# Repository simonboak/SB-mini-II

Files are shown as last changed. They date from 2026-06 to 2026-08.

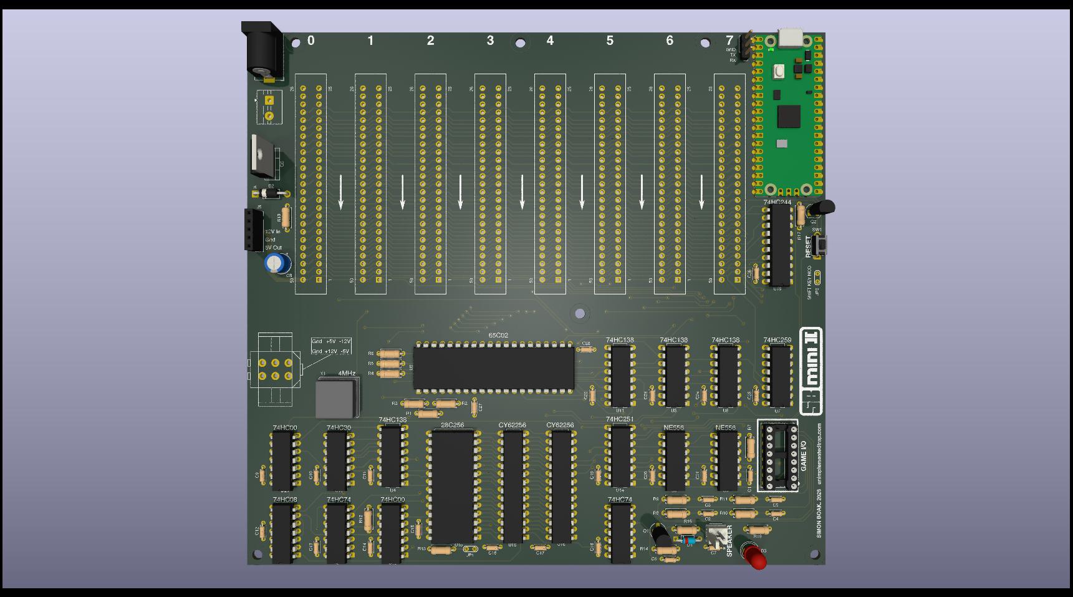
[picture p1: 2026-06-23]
Images/SB mini II Board Render.jpg

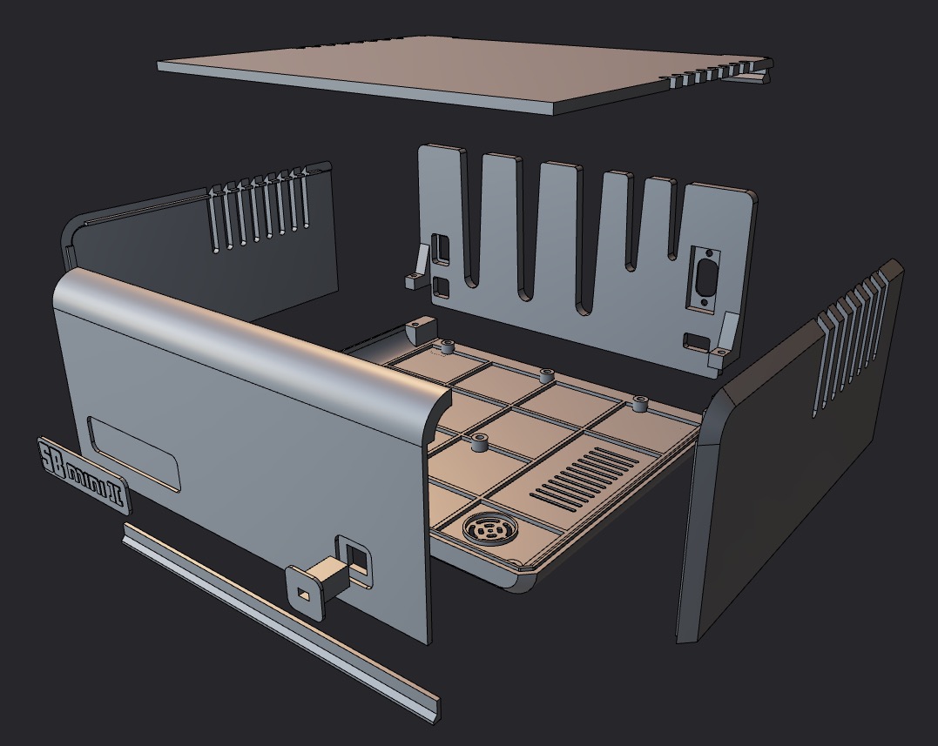
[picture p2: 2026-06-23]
Enclosure/Exploded View.jpg

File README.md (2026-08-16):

# SB mini II
A homebrewed Apple II clone. [Read more on the blog post](https://unimplementedtrap.com/sb-mini-ii-apple-ii-clone/)

SB mini II Logo

SB mini II cutaway

## Hardware Overview

- The CPU is a standard 65C02 running at near 1.024 MHz (the original Apple II ran at 1.023 for the 60 Hz models), after dividing the 4.096 MHz crystal by 4.
- The 12kB ROM image is placed on the 32k EEPROM. Because there's spare room on this chip a jumper allows for selecting the high or low half of the ROM chip, so I've placed Ardian Black's [Deadtest](https://github.com/misterblack1/appleII_deadtest) program in there.
- 48kB of RAM is accomplished by using one and half 32kB SRAM chips. Figured this was easier to use matching chipd than it was to use a 32kb + 16kB chip.
- Address decoding works exactly like the real Apple II. This was mostly based on the schematics in _Understanding The Apple II_ by Jim Sather.
- In Addition to the I/O slots, this has:
  - Speaker: matching the genuine Apple II
  - Game I/O: as the NE558 quad timer is hard to find, I've [implemented this replacement using a pair of 556 chips](https://github.com/roybaer/ne558_replacement).
  - Keyboard: a Raspberry Pi Pico provides a modern USB interface but electrically it connects to the Apple II in the same way as the original ASCII keyboard did. The Pi can also generate a reset pulse when pressing Control + Print Screen, and also performs a power-on reset for the system. The firmware for this is [in this project here](https://github.com/simonboak/SB-mini-II-Keyboard).
  - Graphics: there is absolutely no onboard hardware for displaying graphics. Instead you'll want to use an [Apple VGA Card](https://github.com/markadev/AppleII-VGA).
- Features deliberately missing:
  - Expansion slots do not provide the DMA, USER 1 or 7M clock signals.
  - The bus is not buffered: with a CMOS design this is less likely to be a problem (although no guarantees for interfacing with cards using 74LS logic).
  - There is no cassette input or output.
- These are the Revision 1 files. Rev 0 was a smaller board with no 5V regulation, only 7 slots and 32k on board RAM. The plan had been to leave out slot 0 and work out how to make full use of a second 32k RAM chip to have the full 64k without needing a language card, however this almost doubled the amount of circuitry needed.

SB mini II Board Render

## 3D Printed Case

Combining the design of the Apple II with the ProFile hard disk, the case requires a bit of assembly:

1. Print each piece with the flat side on the print bad (you could print the lid pieces as one if desired)
2. Glue the "tongue" into the slot along the bottom inside edge of the front piece. This will locate into the notch inside the front of the base.
3. Glue the top, front and sides together.
4. For the light pipe it was filled with hot glue to create a diffused lense with the LED glued in behind.
5. The base requires 8x M3 threaded inserts, 2 of which are for the back panel, the rest are the PCB mounts.
6. The 20mm speaker can be taped into the round hole in the base.

Assembled
Exploded View

### Rear with reset switch

An alernative file for the rear panel of the case is included. This contains a 7mm hole for a suitably sized push button switch.

### Rev 1 Update:

Alternative files are provided for the lid: this greatly reduces the radius of the curve on the front of the case. This should print better and without requiring so much filling and sanding, although it does depart from the styling inspiration of the ProFile hard disk.

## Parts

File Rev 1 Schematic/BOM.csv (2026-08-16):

Reference | Value | Qty
A1 | Raspberry Pi Pico 1 | 1
C1,C6,C7,C9,C10,C11,C12,C13,C14,C15,C16,C17,C18,C19,C20,C21,C22,C23,C24,C25,C26,C27,C28,C29 | 0.1µF | 24
C2,C3,C4,C5 | 22nF | 4
C8 | 470µF | 1
D1 | 1N914 | 1
D2 | 1N5240B | 1
D3 | 3 or 5mm power indicator LED | 1
J1 | GAME I/O: DIP-16 socket | 1
J2 | Pico Debug: 3 pin header | 1
J3 | PCB Barrel Jack | 1
J4 | Terminal block for power switch | 1
J5 | Pololu 5V 1A Step-Down Voltage Regulator (D24V10F5) | 1
J6 | Apple II Power Connector | 1
JP1 | HI ROM selector: 2 pin header | 1
JP2 | SHIFT KEY MOD: 2 pin header | 1
LS1 | Speaker 20mm 0.5W | 1
Q1 | MPSA13 | 1
Q2 | PN2222A | 1
Q3 | IRF5305 | 1
R1,R2,R3,R4,R5,R12 | 3k3 | 6
R6,R17 | 1k | 3
R7 | 2k5 | 1
R8,R9,R10,R11 | 100 | 4
R13 | 10K | 1
R14 | 47k | 1
R15 | 27 | 1
R18 | 100k | 1
R19 | 330 | 1
Slot1,Slot2,Slot3,Slot4,Slot5,Slot6,Slot7,Slot8 | 50 pin card edge connector | 8
SW1 | RESET: MJTP/PHAP33 tactile switch | 1
U1,U13 | 74HC74 | 2
U2 | 65C02 | 1
U3 | 74HC08 | 1
U4,U5,U6 | 74HC138 | 3
U7 | 74HC259 | 1
U8,U9 | NE556 | 2
U10 | 74HC30 | 1
U11 | 74HCT138 | 1
U12,U17 | 74HC00 | 2
U14 | 74HC251 | 1
U15 | 28C256 32k x 8 EEPROM | 1
U16,U18 | CY62256 32k x 8 SRAM | 2
U19 | 74HC244 | 1
Y1 | 4MHz square can crystal oscillator | 1

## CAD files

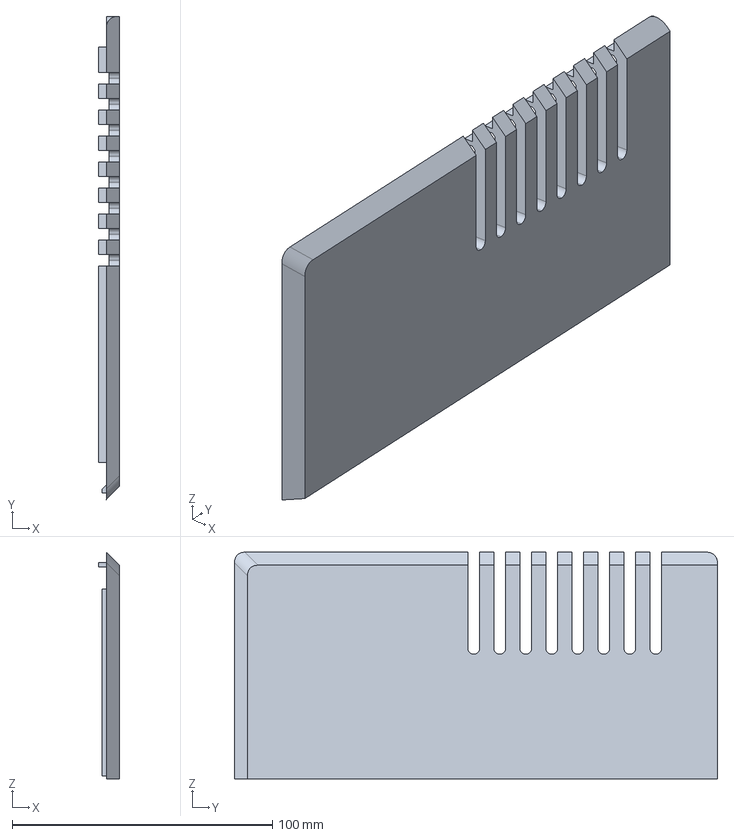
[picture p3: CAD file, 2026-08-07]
Enclosure/Lid Rev 1/Right Side - Rev 1.stp
8.00 x 185.7 x 87.1 mm

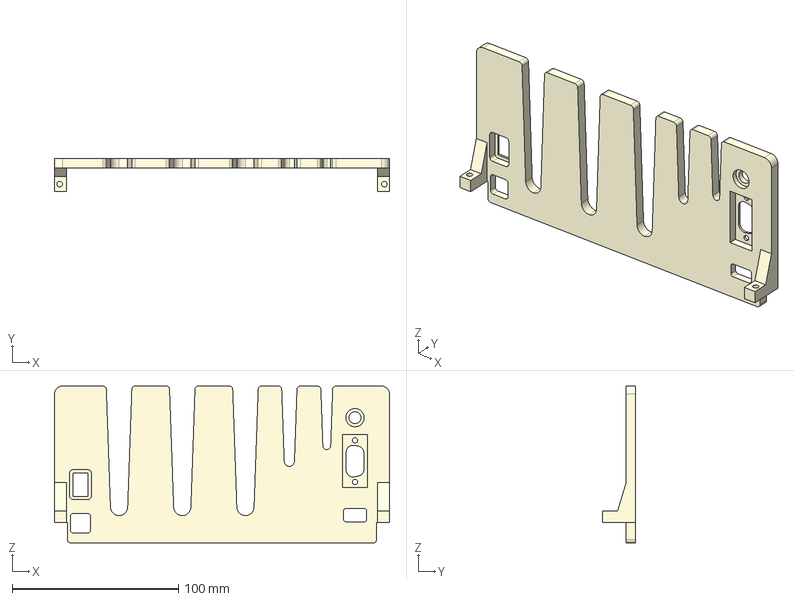
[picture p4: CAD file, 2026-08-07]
Enclosure/Rear with Reset Switch.stp
201.4 x 20.0 x 94.3 mm

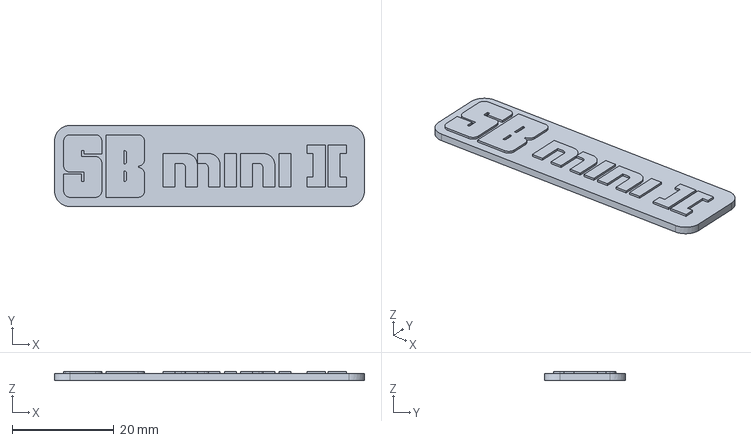
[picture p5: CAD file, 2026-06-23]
Enclosure/Badge.stp
61.0 x 16.0 x 1.80 mm

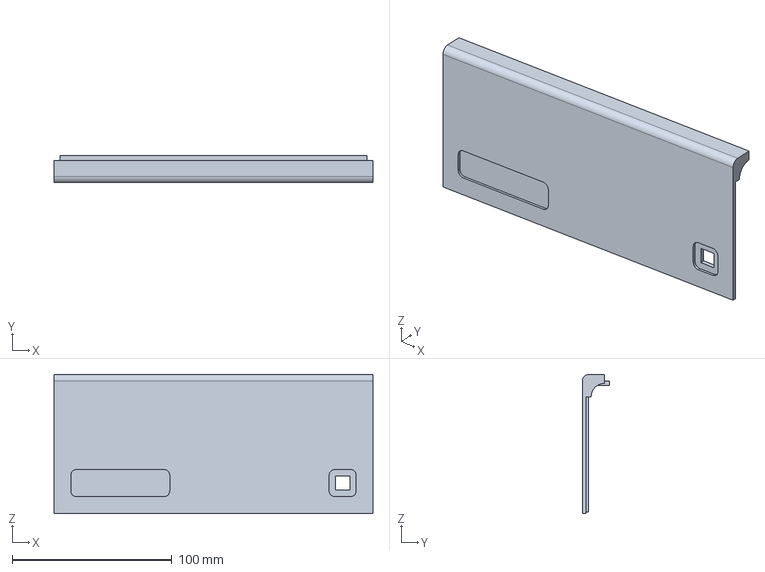
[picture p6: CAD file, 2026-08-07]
Enclosure/Lid Rev 1/Front - Rev 1.stp
199.8 x 17.1 x 87.1 mm

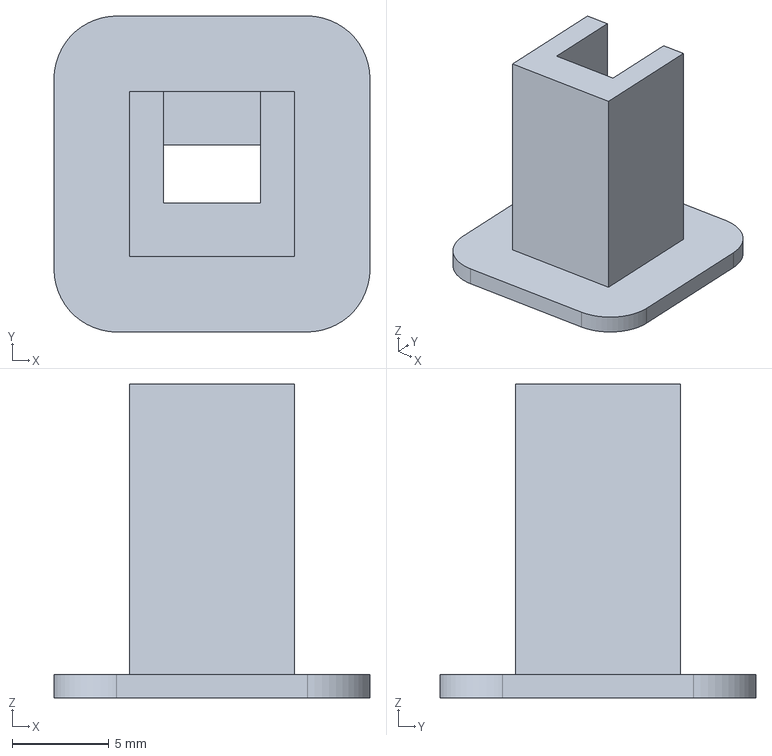
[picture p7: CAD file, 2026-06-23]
Enclosure/Light Pipe.stp
16.3 x 16.3 x 16.2 mm

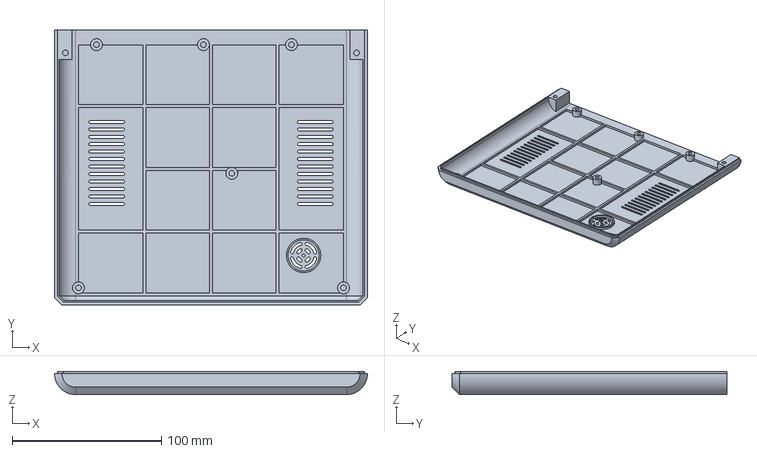
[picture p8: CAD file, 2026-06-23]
Enclosure/Base.stp
210.0 x 184.7 x 15.5 mm

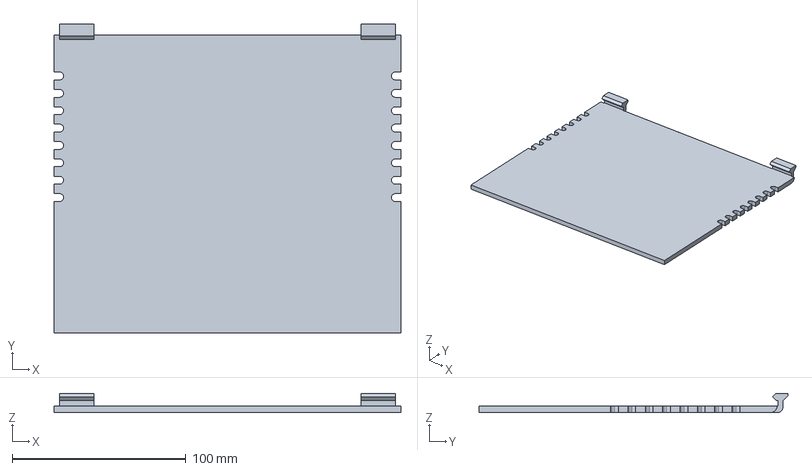
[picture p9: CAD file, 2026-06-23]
Enclosure/Lid Rev 1/Lid - Rev 1.stp
199.8 x 178.0 x 11.1 mm

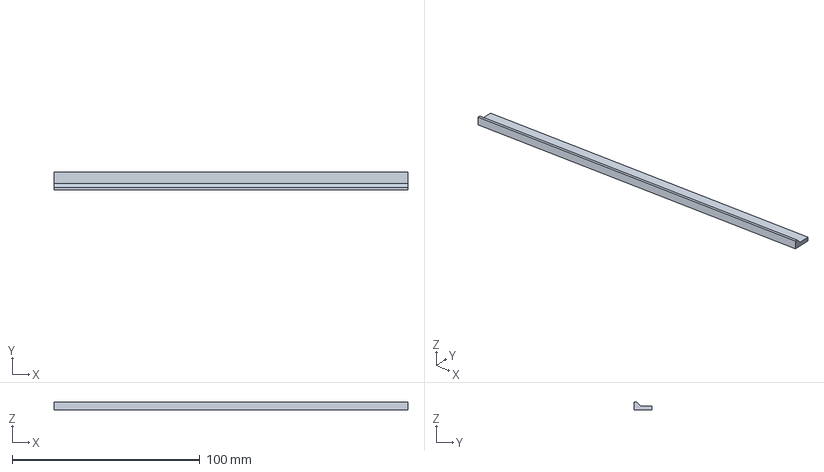
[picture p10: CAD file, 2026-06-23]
Enclosure/Lid Rev 1/Tongue - Rev 1.stp
188.6 x 9.50 x 4.14 mm

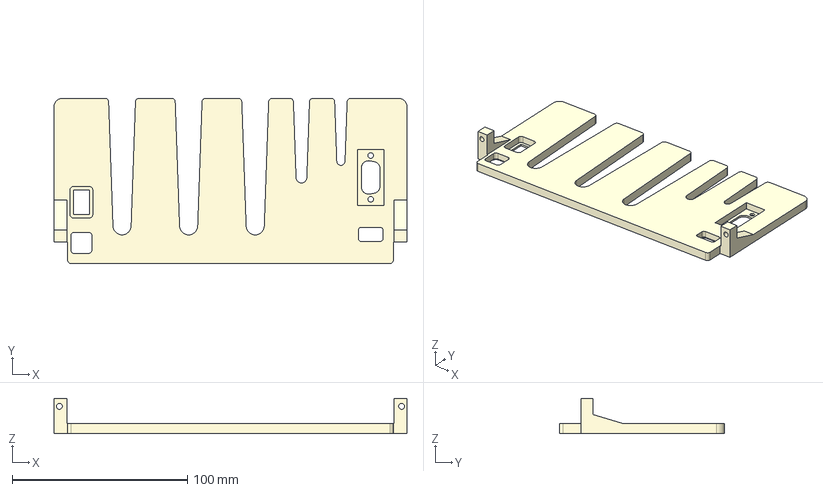
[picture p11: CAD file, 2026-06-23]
Enclosure/Rear.stp
201.4 x 94.4 x 20.0 mm

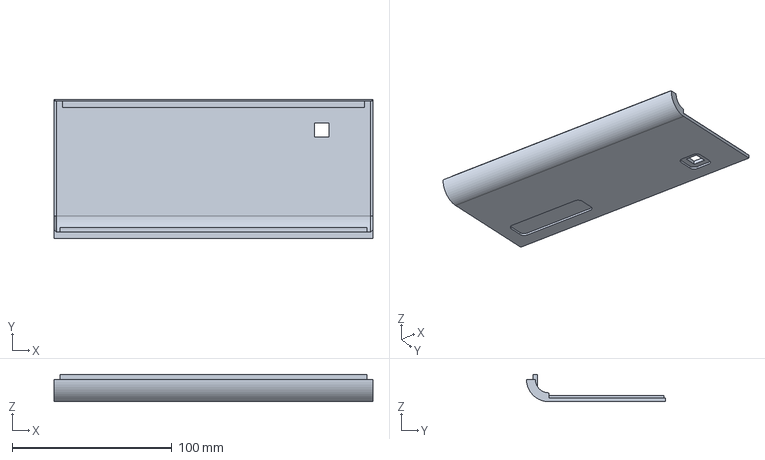
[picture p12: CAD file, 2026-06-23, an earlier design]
Enclosure/Lid Rev 0/Front.stp
199.8 x 87.1 x 17.1 mm

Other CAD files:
Enclosure/Lid Rev 1/Left Side - Rev 1.stp
Enclosure/Lid Rev 0/Left Side.stp
Enclosure/Lid Rev 0/Right Side.stp

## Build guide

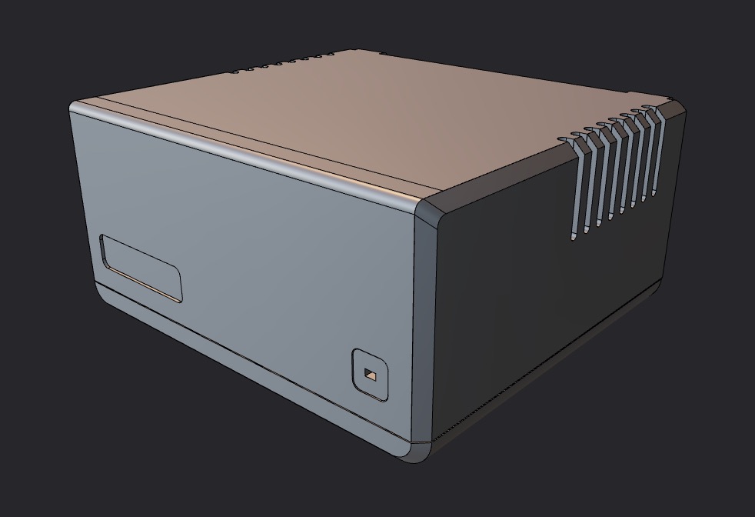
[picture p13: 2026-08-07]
Enclosure/Assembled - Rev 1.jpg

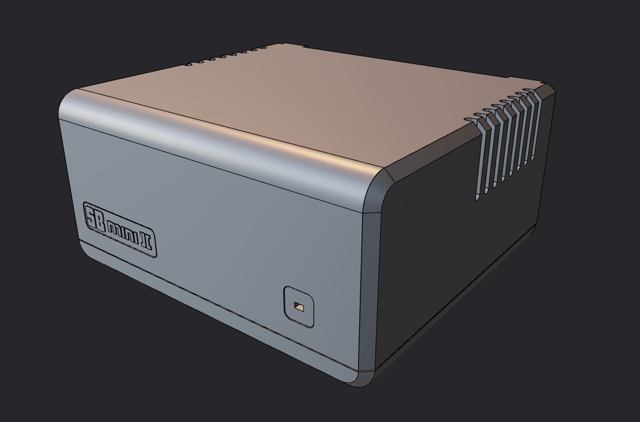
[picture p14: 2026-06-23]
Enclosure/Assembled.jpg

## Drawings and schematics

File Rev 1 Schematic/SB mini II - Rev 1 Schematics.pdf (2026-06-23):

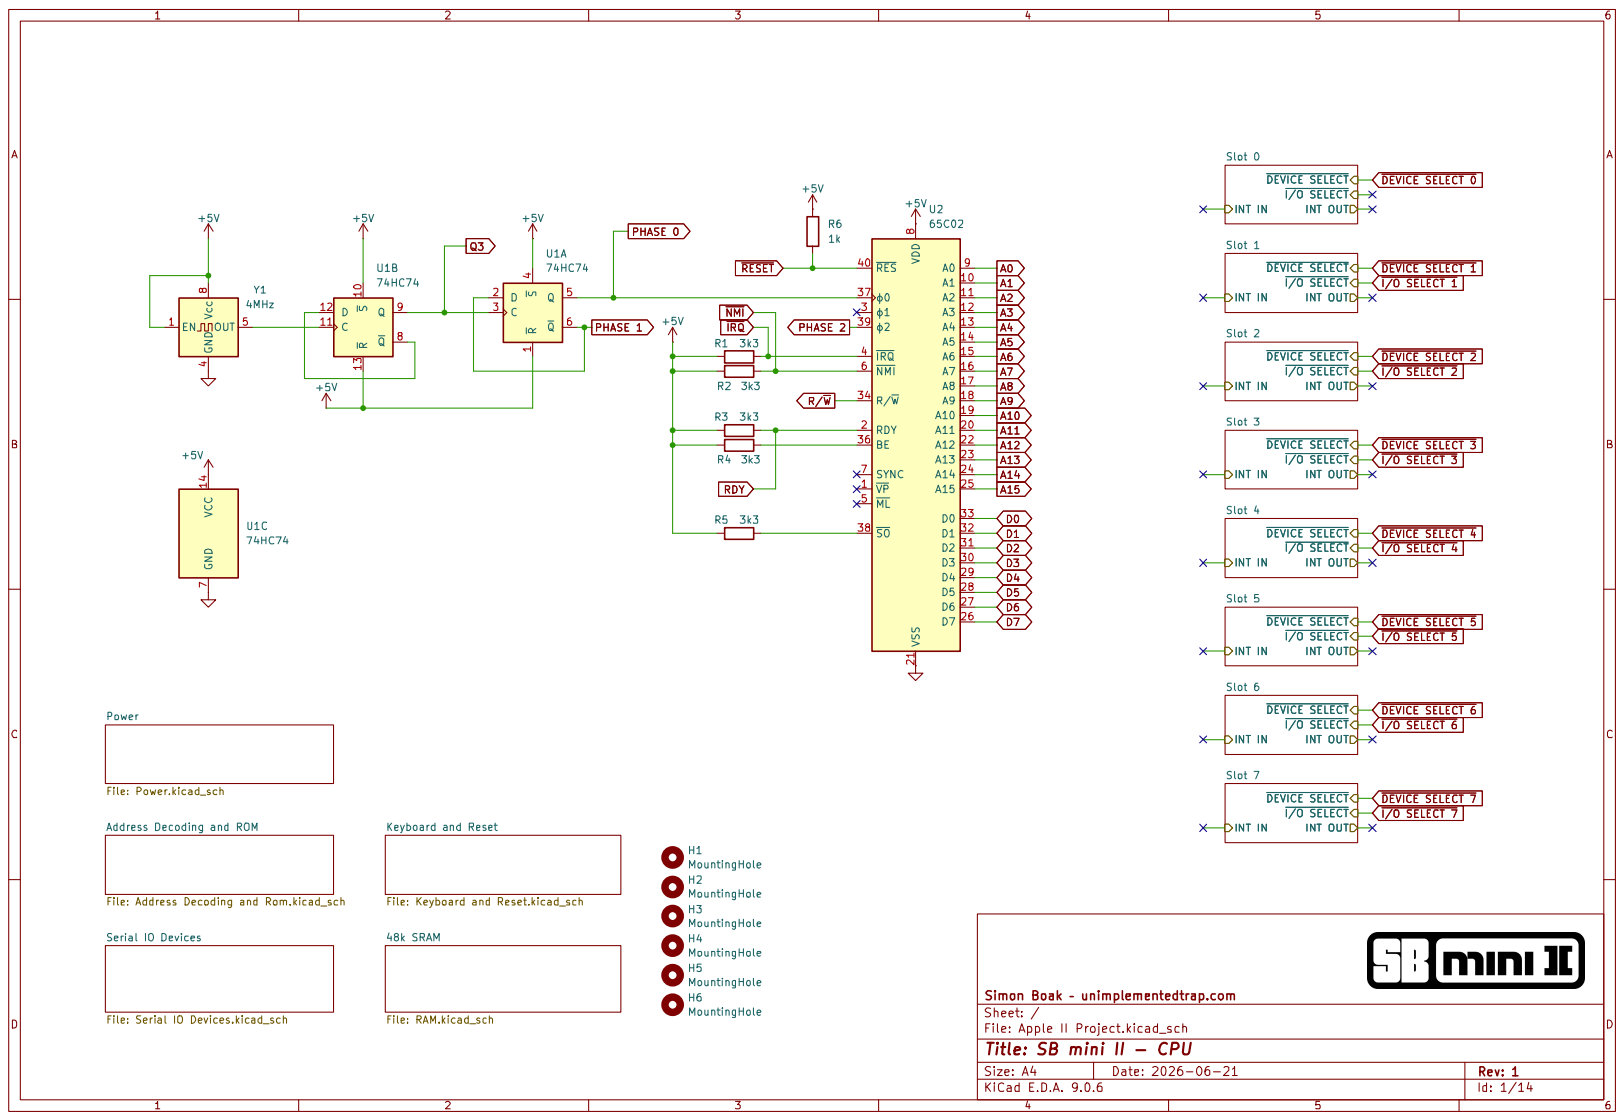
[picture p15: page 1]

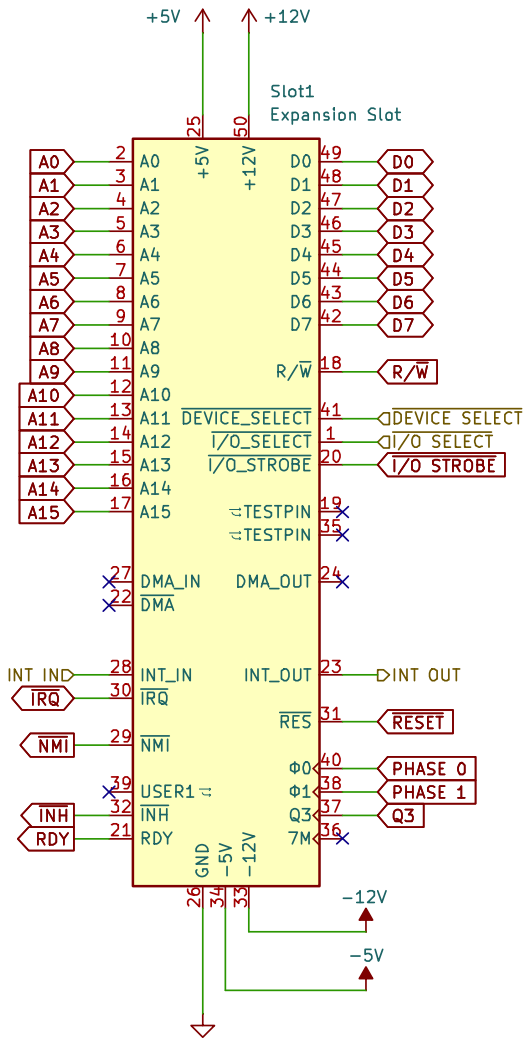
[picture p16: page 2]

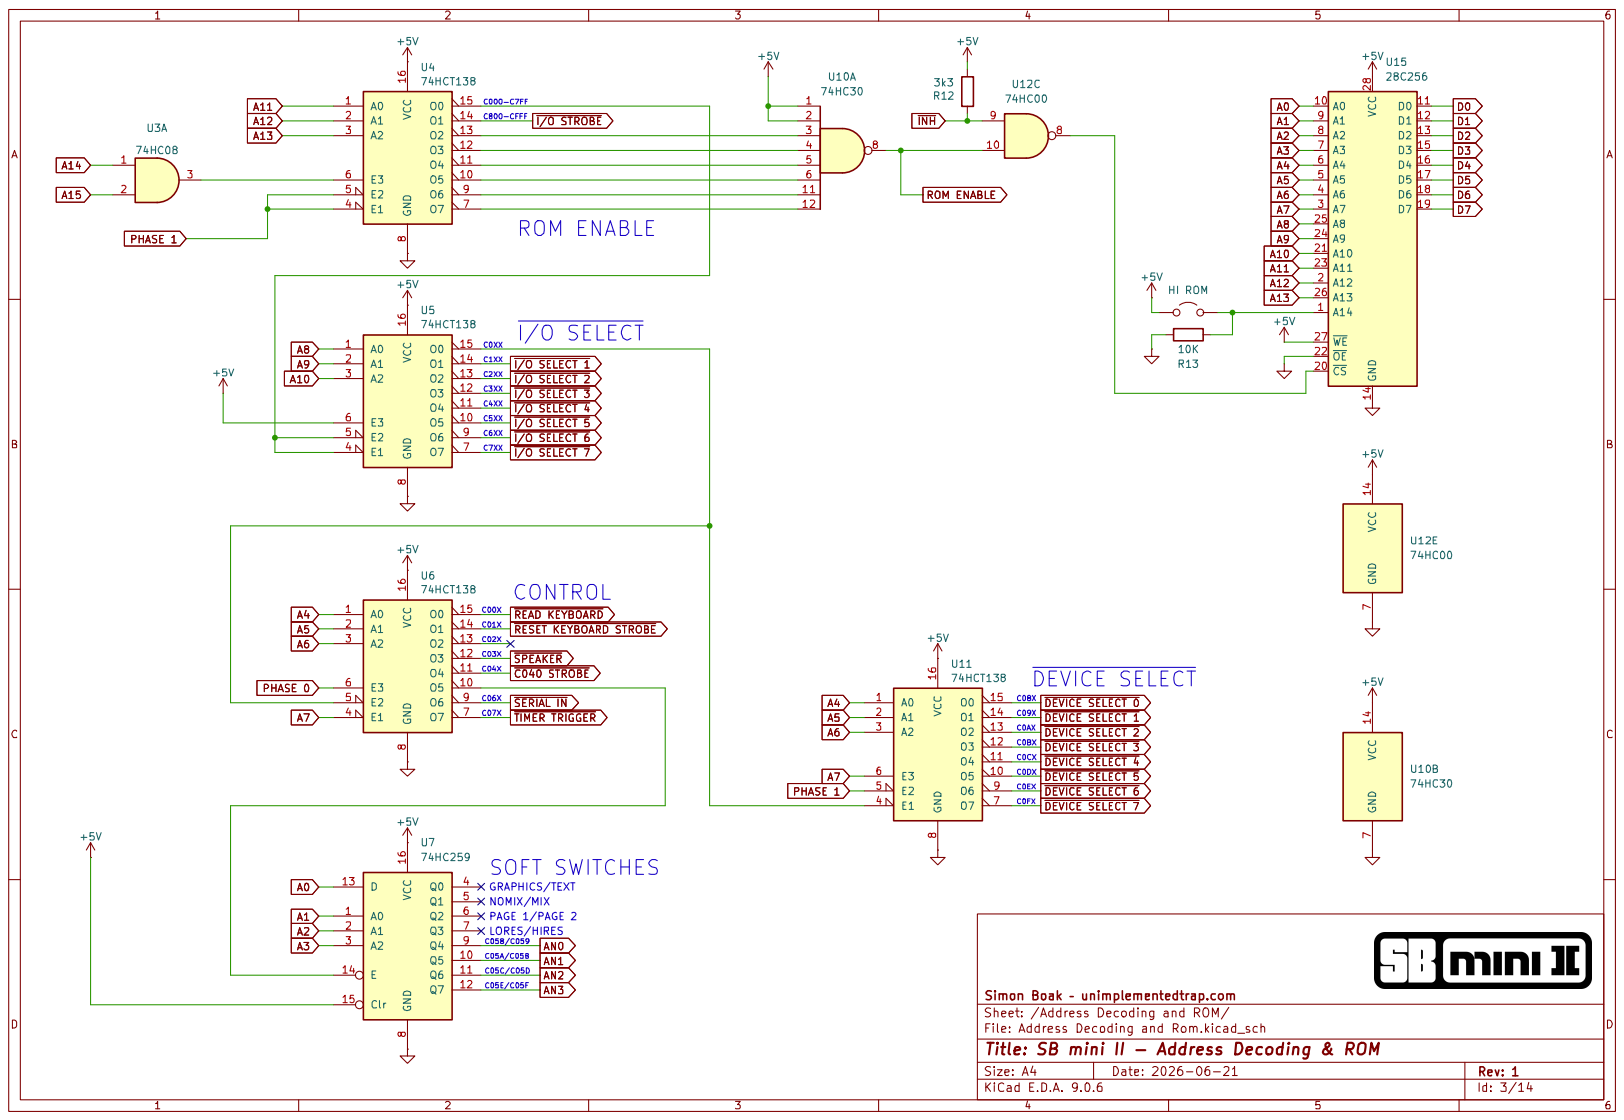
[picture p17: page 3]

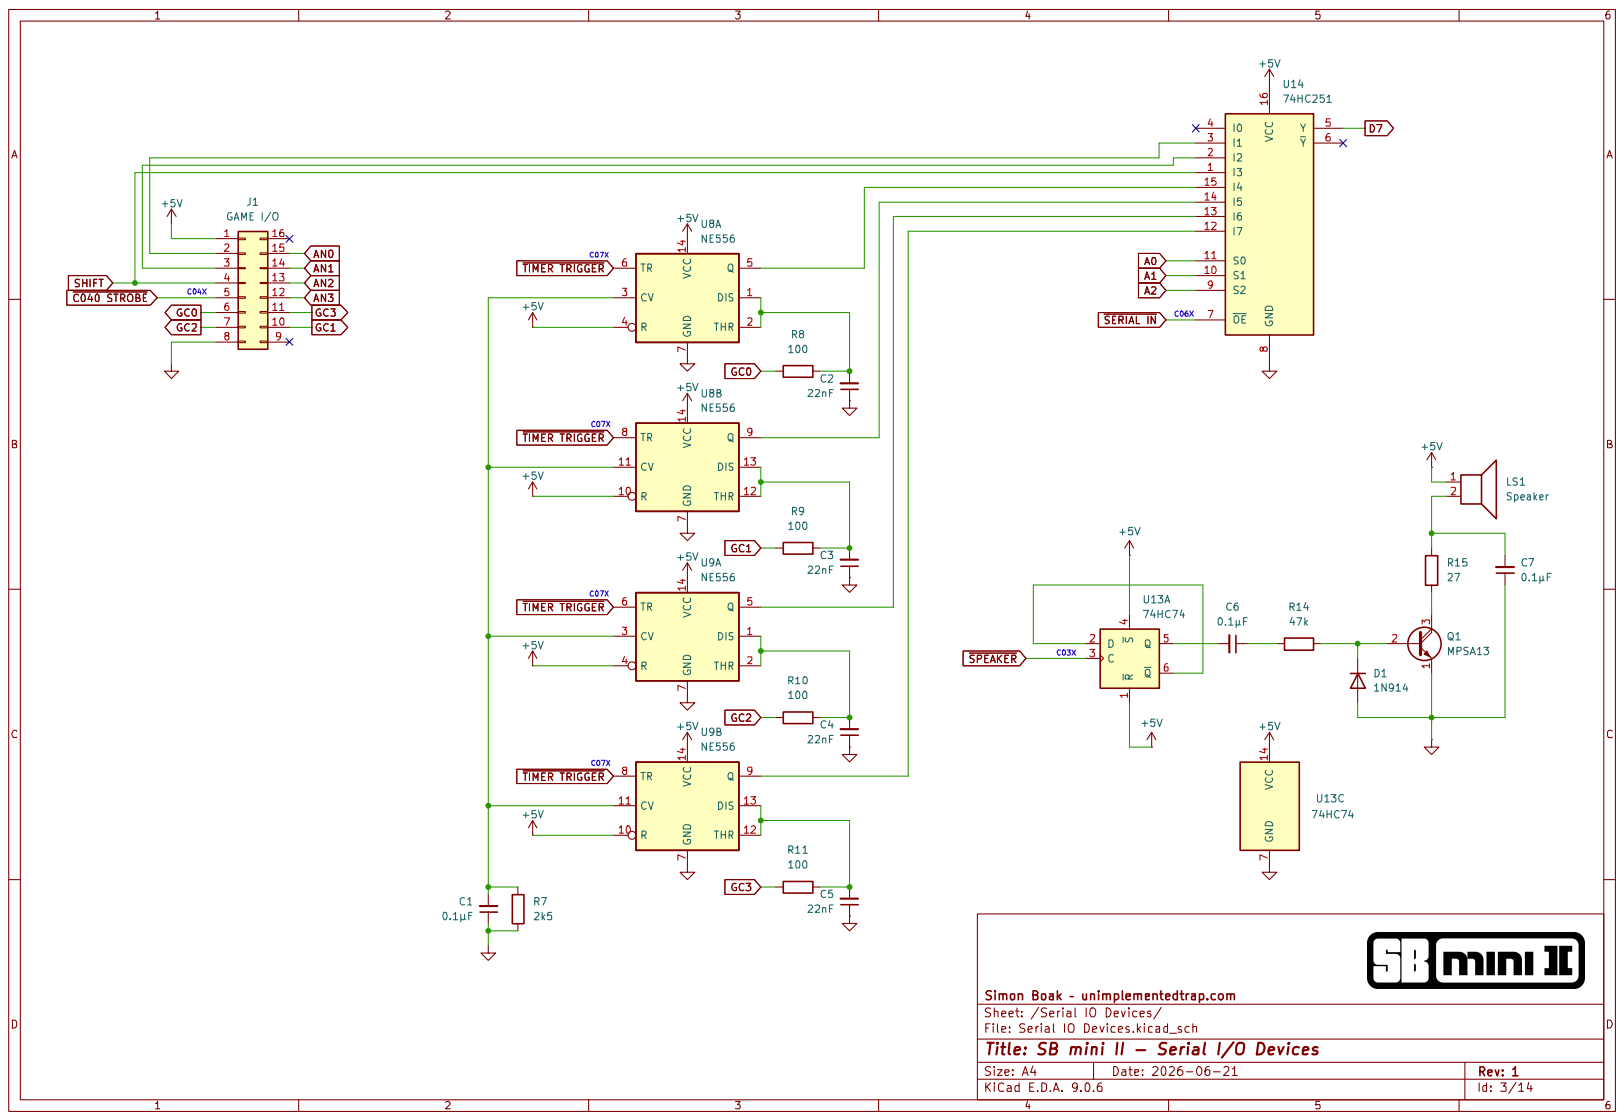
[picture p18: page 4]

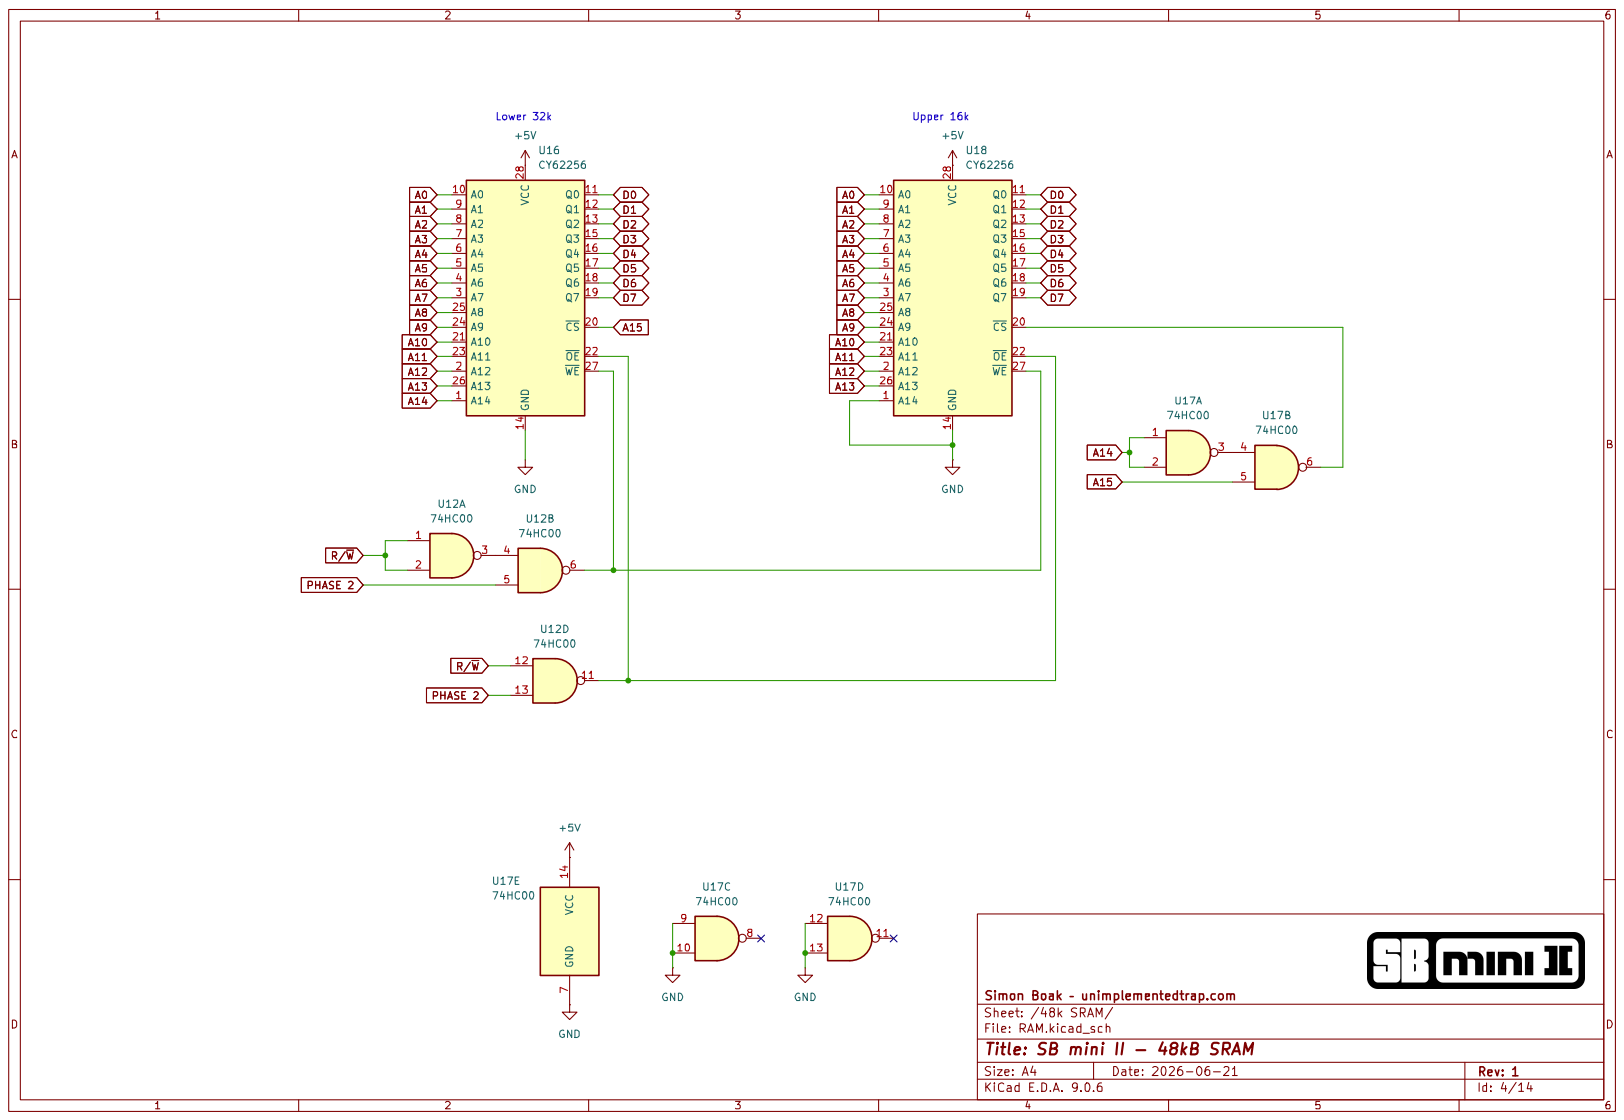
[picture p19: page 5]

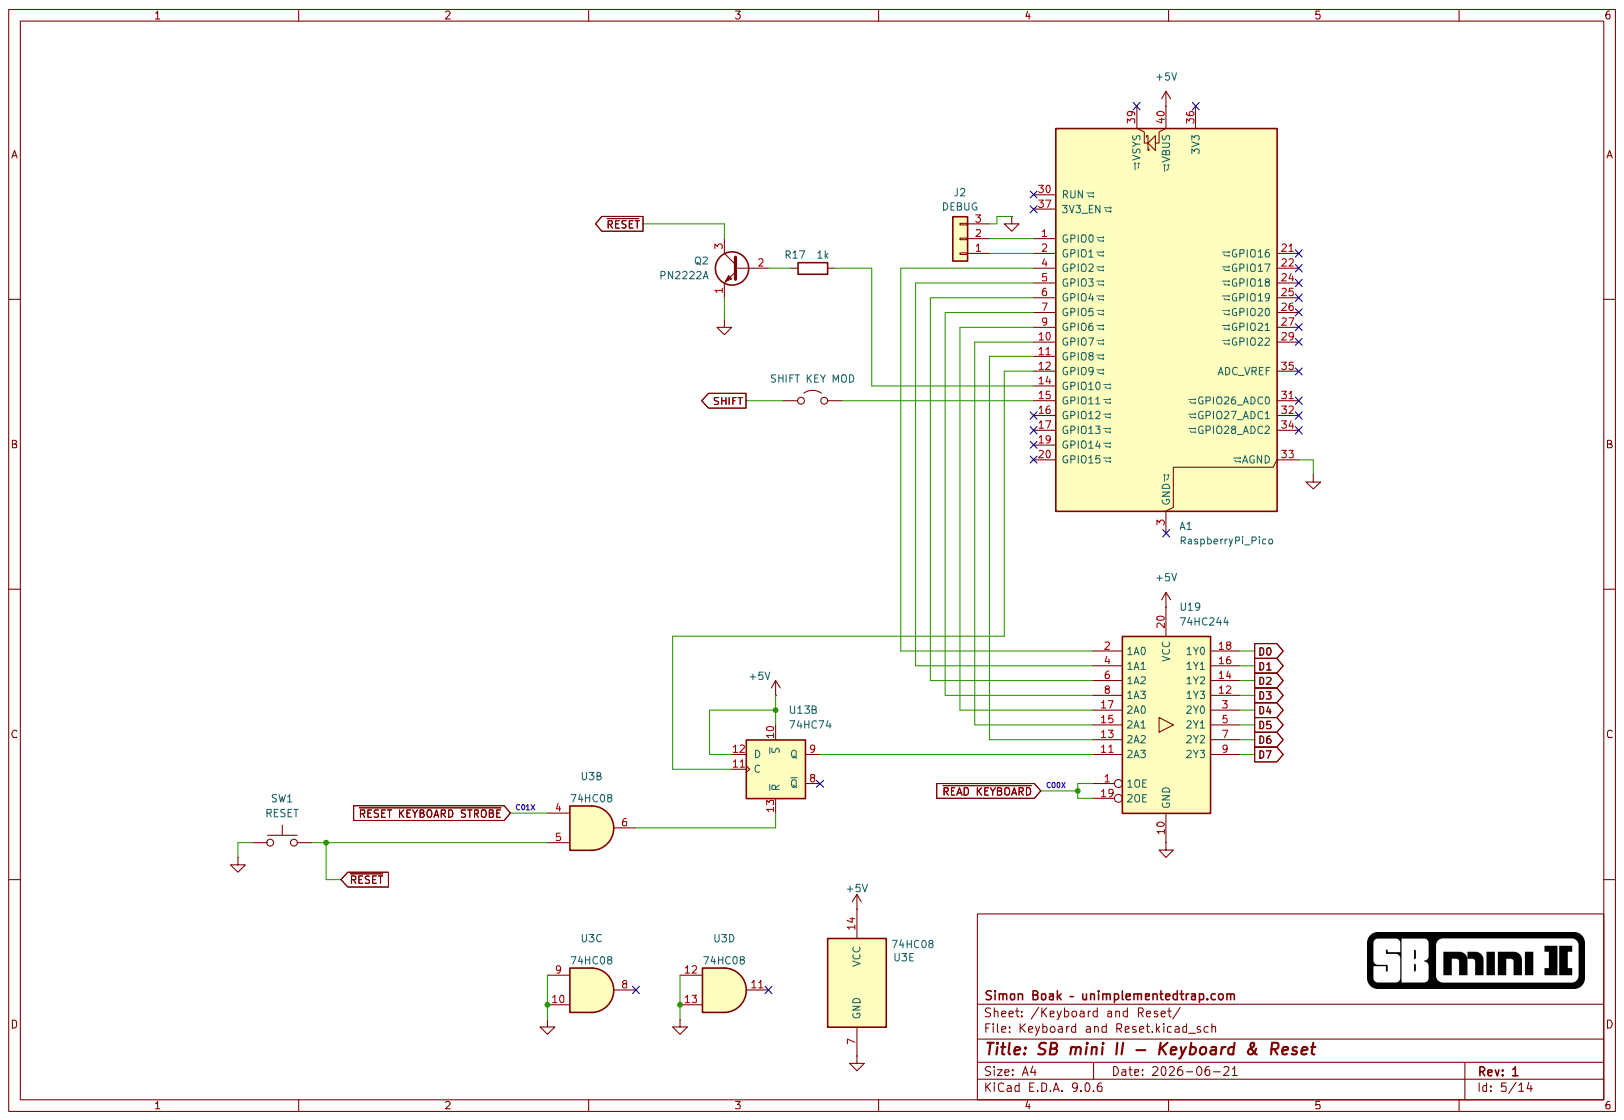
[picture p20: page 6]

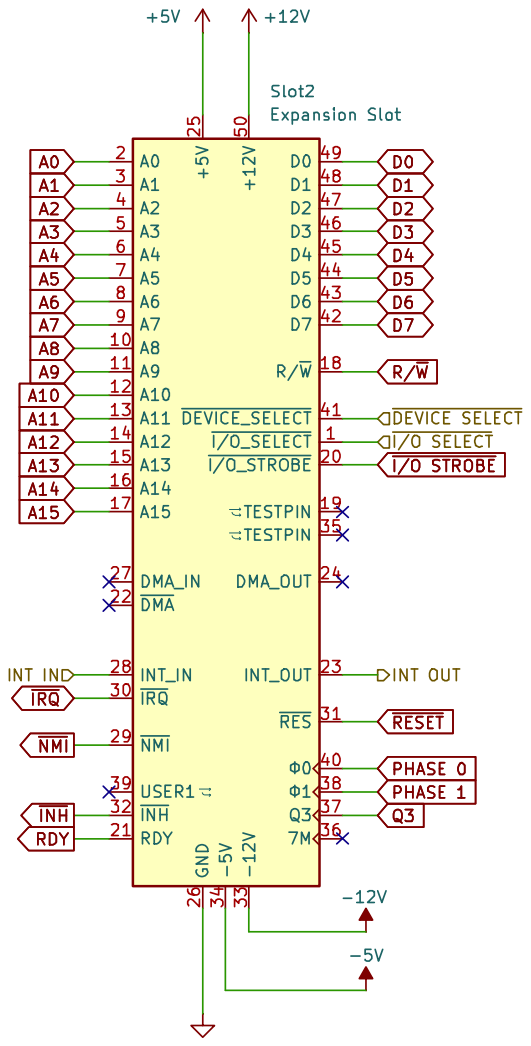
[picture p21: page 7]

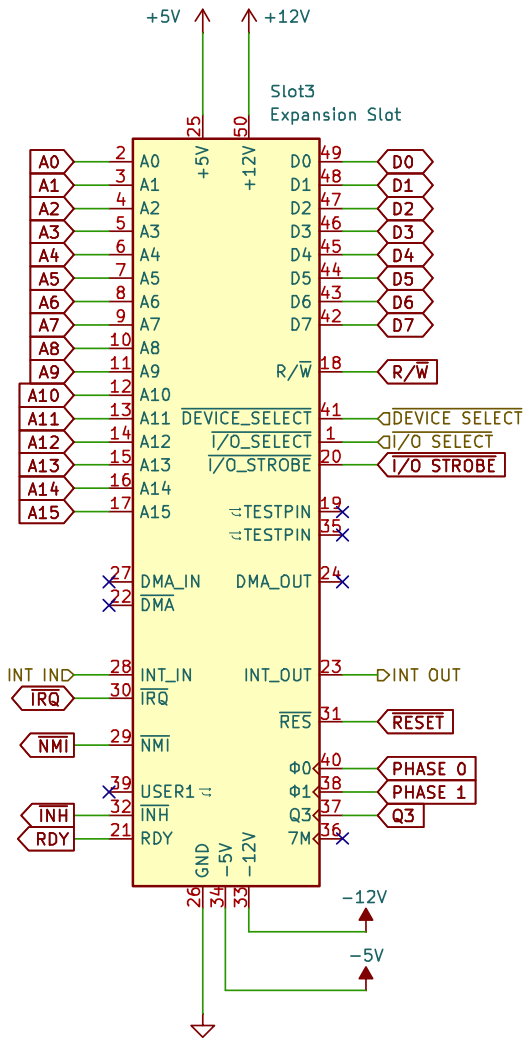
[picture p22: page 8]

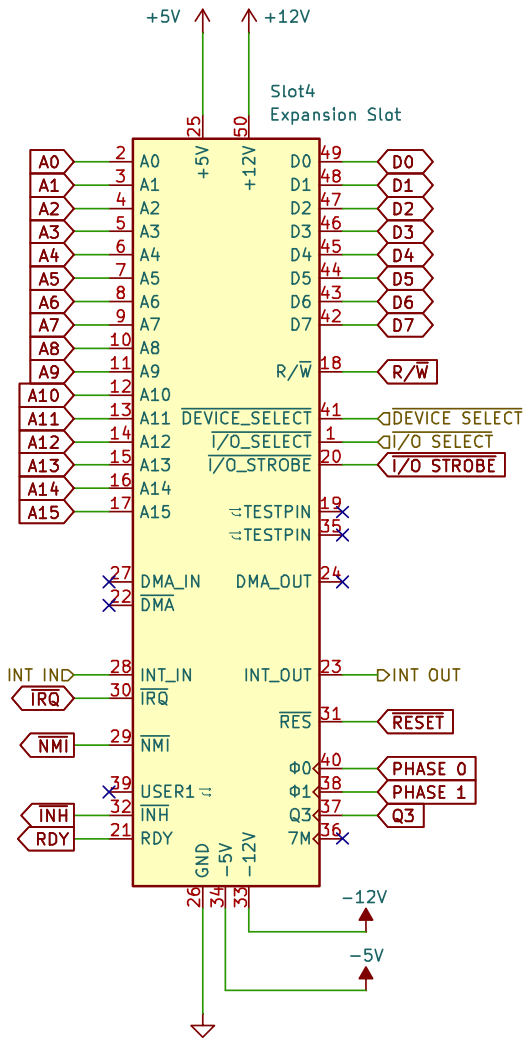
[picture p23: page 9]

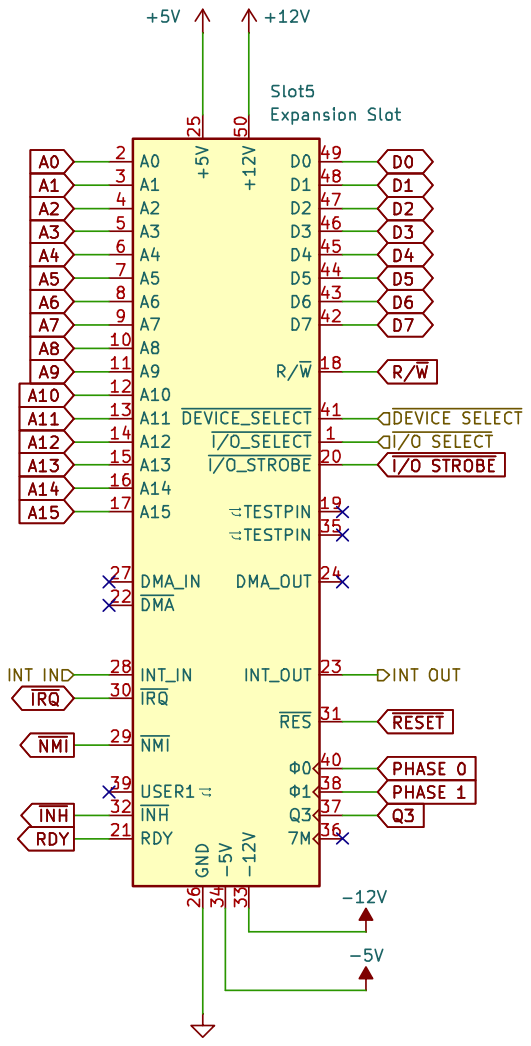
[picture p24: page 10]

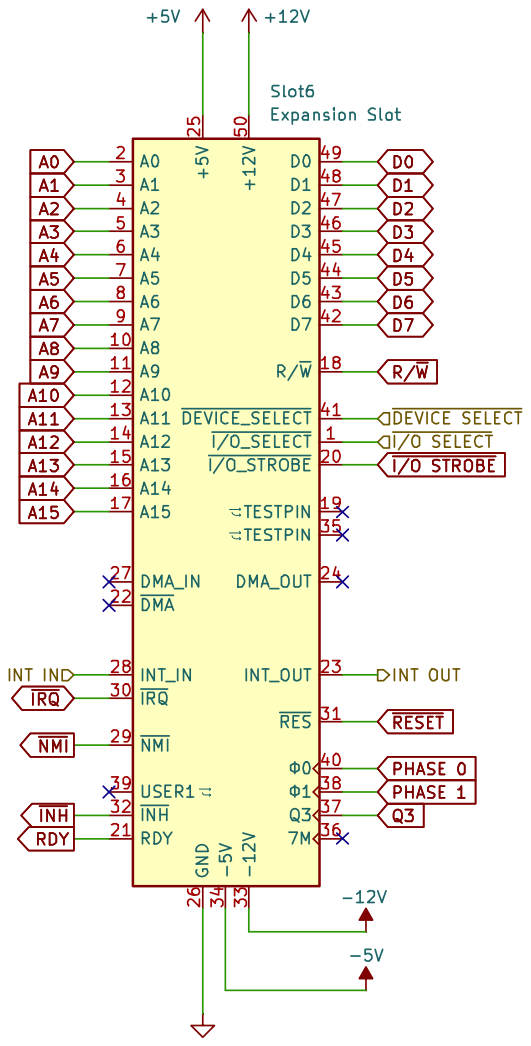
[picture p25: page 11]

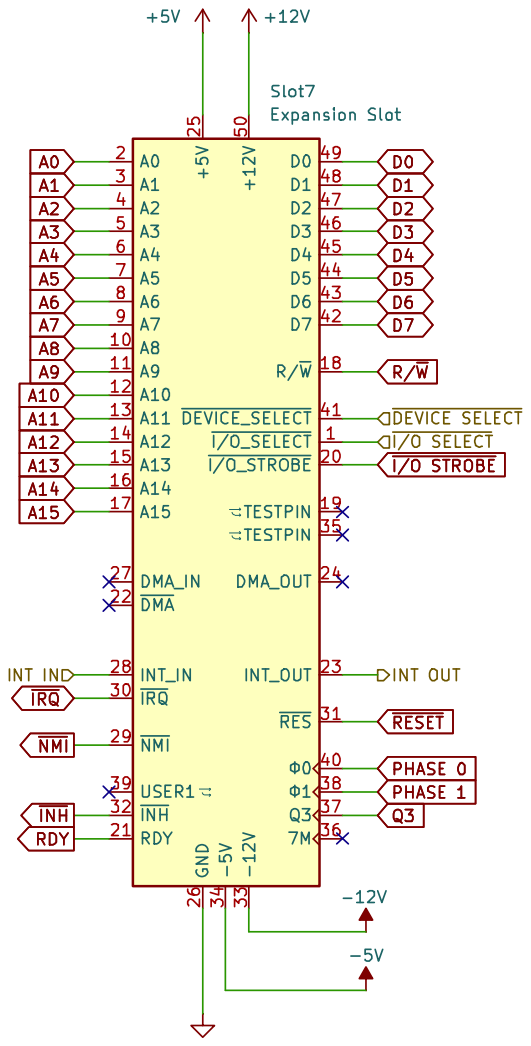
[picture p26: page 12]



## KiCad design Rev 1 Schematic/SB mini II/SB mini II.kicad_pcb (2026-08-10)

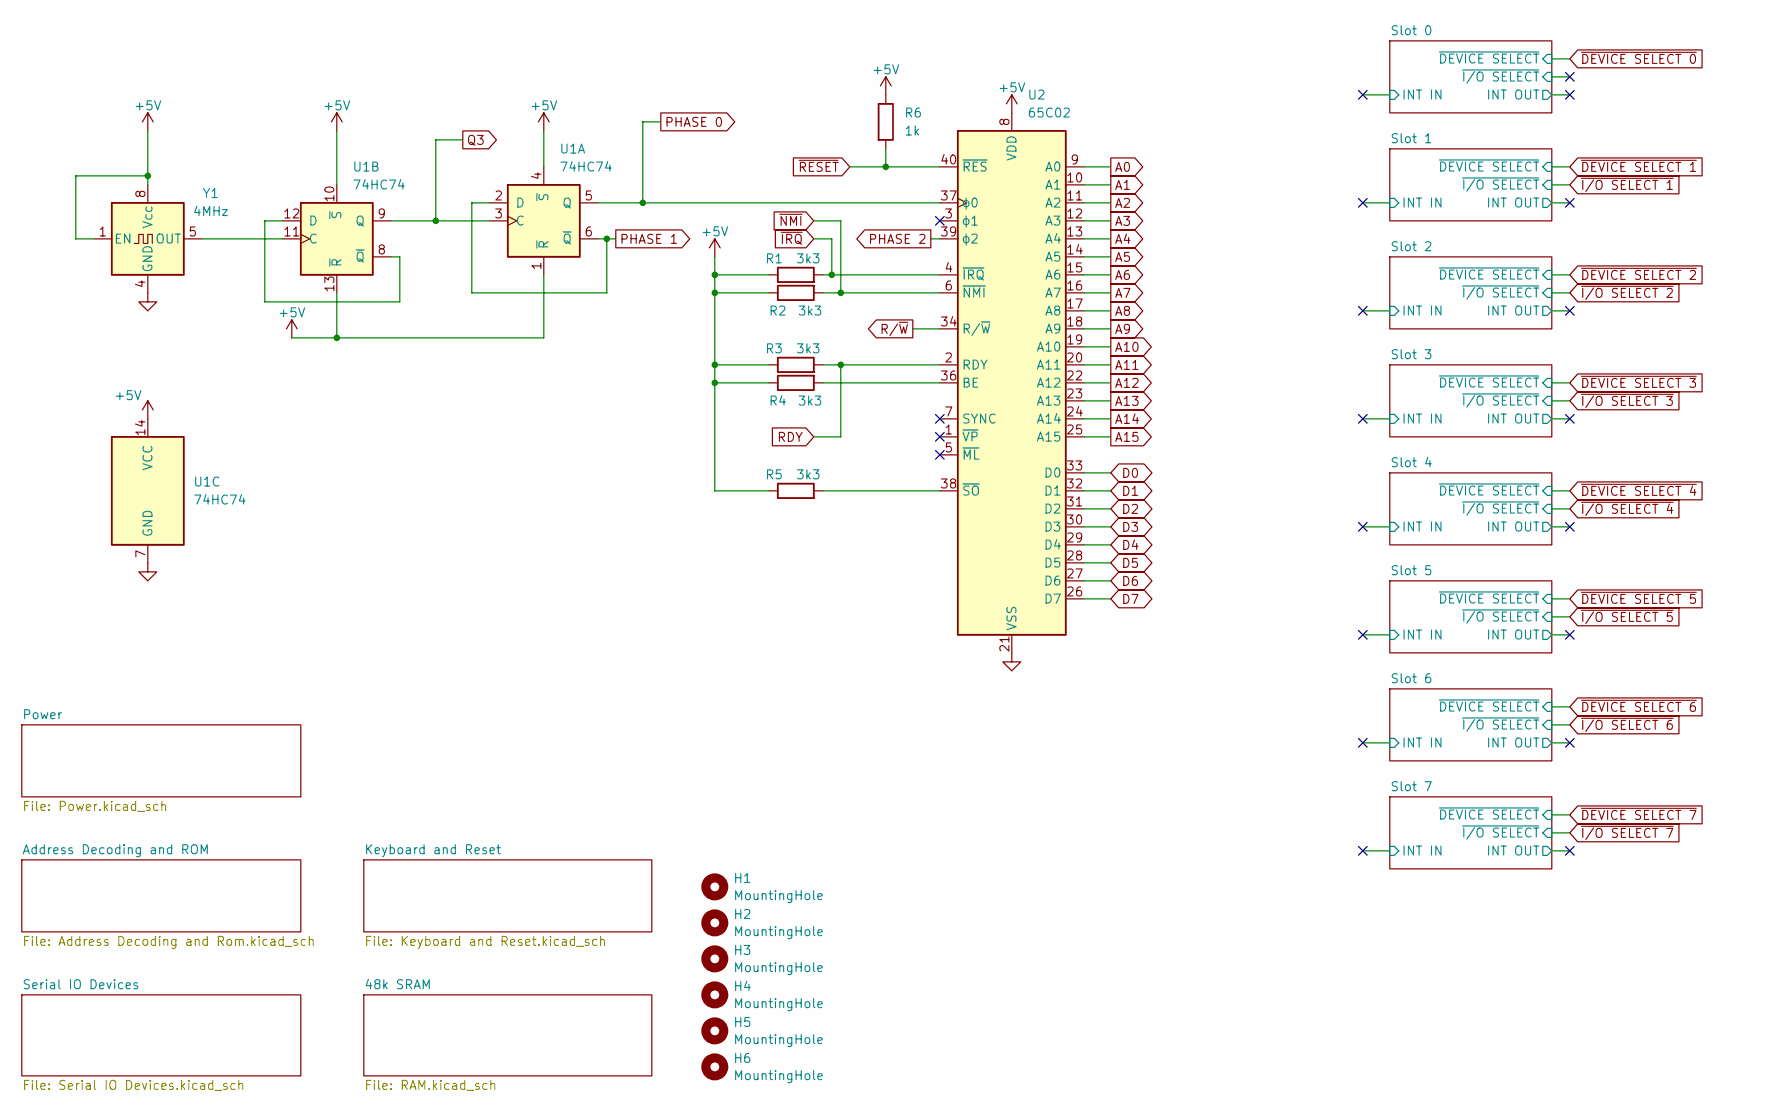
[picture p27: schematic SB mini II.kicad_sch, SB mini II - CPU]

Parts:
H1, H2, H3, H4, H5, H6: MountingHole; MountingHole_3.2mm_M3
R1, R2, R3, R4, R5: 3k3; R_Axial_DIN0207_L6.3mm_D2.5mm_P7.62mm_Horizontal
R6: 1k; R_Axial_DIN0207_L6.3mm_D2.5mm_P7.62mm_Horizontal
U1: 74HC74; DIP-14_W7.62mm_LongPads
U2: 65C02; DIP-40_W15.24mm
Y1: 4MHz; Oscillator_DIP-8

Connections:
+5V: R1.1, R2.1, R3.1, R4.1, R5.1, R6.1, U1.1 (~R), U1.4 (~S), U1.10 (~S), U1.13 (~R), U1.14 (VCC), U2.8 (VDD), Y1.1 (EN), Y1.8 (Vcc); also elsewhere on the board
A0: U2.9 (A0); also elsewhere on the board
A1: U2.10 (A1); also elsewhere on the board
A2: U2.11 (A2); also elsewhere on the board
A3: U2.12 (A3); also elsewhere on the board
A4: U2.13 (A4); also elsewhere on the board
A5: U2.14 (A5); also elsewhere on the board
A6: U2.15 (A6); also elsewhere on the board
A7: U2.16 (A7); also elsewhere on the board
A8: U2.17 (A8); also elsewhere on the board
A9: U2.18 (A9); also elsewhere on the board
A10: U2.19 (A10); also elsewhere on the board
A11: U2.20 (A11); also elsewhere on the board
A12: U2.22 (A12); also elsewhere on the board
A13: U2.23 (A13); also elsewhere on the board
A14: U2.24 (A14); also elsewhere on the board
A15: U2.25 (A15); also elsewhere on the board
D0: U2.33 (D0); also elsewhere on the board
D1: U2.32 (D1); also elsewhere on the board
D2: U2.31 (D2); also elsewhere on the board
D3: U2.30 (D3); also elsewhere on the board
D4: U2.29 (D4); also elsewhere on the board
D5: U2.28 (D5); also elsewhere on the board
D6: U2.27 (D6); also elsewhere on the board
D7: U2.26 (D7); also elsewhere on the board
GND: U1.7 (GND), U2.21 (VSS), Y1.4 (GND); also elsewhere on the board
unnamed: U1.11 (C), Y1.5 (OUT)
unnamed: U1.8 (~Q), U1.12 (D)
unnamed: R4.2, U2.36 (BE)
unnamed: R5.2, U2.38 (~SO)
PHASE 0: U1.5 (Q), U2.37 (ϕ0); also elsewhere on the board
PHASE 1: U1.2 (D), U1.6 (~Q); also elsewhere on the board
PHASE 2: U2.39 (ϕ2); also elsewhere on the board
Q3: U1.3 (C), U1.9 (Q); also elsewhere on the board
RDY: R3.2, U2.2 (RDY); also elsewhere on the board
R/~W: U2.34 (R/~W); also elsewhere on the board
~IRQ: R1.2, U2.4 (~IRQ); also elsewhere on the board
~NMI: R2.2, U2.6 (~NMI); also elsewhere on the board
~RESET: R6.2, U2.40 (~RES); also elsewhere on the board

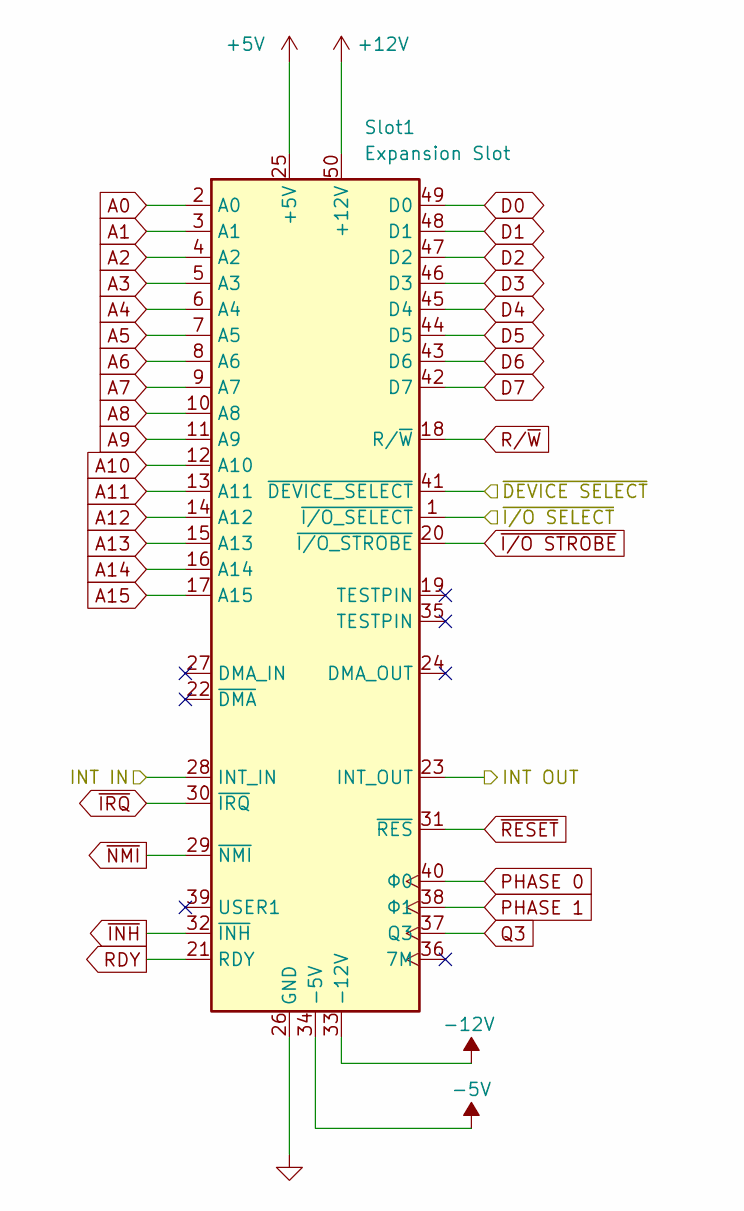
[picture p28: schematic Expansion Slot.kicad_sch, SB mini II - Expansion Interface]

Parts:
Slot1: Expansion Slot; EDAC_395-050-520-201_CounterClockwise

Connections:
+5V: Slot1.25 (+5V); also elsewhere on the board
+12V: Slot1.50 (+12V); also elsewhere on the board
-5V: Slot1.34 (-5V); also elsewhere on the board
-12V: Slot1.33 (-12V); also elsewhere on the board
/Slot 1/INT IN: Slot1.28 (INT_IN)
/Slot 1/INT OUT: Slot1.23 (INT_OUT)
A0: Slot1.2 (A0); also elsewhere on the board
A1: Slot1.3 (A1); also elsewhere on the board
A2: Slot1.4 (A2); also elsewhere on the board
A3: Slot1.5 (A3); also elsewhere on the board
A4: Slot1.6 (A4); also elsewhere on the board
A5: Slot1.7 (A5); also elsewhere on the board
A6: Slot1.8 (A6); also elsewhere on the board
A7: Slot1.9 (A7); also elsewhere on the board
A8: Slot1.10 (A8); also elsewhere on the board
A9: Slot1.11 (A9); also elsewhere on the board
A10: Slot1.12 (A10); also elsewhere on the board
A11: Slot1.13 (A11); also elsewhere on the board
A12: Slot1.14 (A12); also elsewhere on the board
A13: Slot1.15 (A13); also elsewhere on the board
A14: Slot1.16 (A14); also elsewhere on the board
A15: Slot1.17 (A15); also elsewhere on the board
D0: Slot1.49 (D0); also elsewhere on the board
D1: Slot1.48 (D1); also elsewhere on the board
D2: Slot1.47 (D2); also elsewhere on the board
D3: Slot1.46 (D3); also elsewhere on the board
D4: Slot1.45 (D4); also elsewhere on the board
D5: Slot1.44 (D5); also elsewhere on the board
D6: Slot1.43 (D6); also elsewhere on the board
D7: Slot1.42 (D7); also elsewhere on the board
GND: Slot1.26 (GND); also elsewhere on the board
PHASE 0: Slot1.40 (Φ0); also elsewhere on the board
PHASE 1: Slot1.38 (Φ1); also elsewhere on the board
Q3: Slot1.37 (Q3); also elsewhere on the board
RDY: Slot1.21 (RDY); also elsewhere on the board
R/~W: Slot1.18 (R/~W); also elsewhere on the board
~DEVICE SELECT 1: Slot1.41 (~DEVICE_SELECT); also elsewhere on the board
~INH: Slot1.32 (~INH); also elsewhere on the board
~IRQ: Slot1.30 (~IRQ); also elsewhere on the board
~I/O SELECT 1: Slot1.1 (~I/O_SELECT); also elsewhere on the board
~I/O STROBE: Slot1.20 (~I/O_STROBE); also elsewhere on the board
~NMI: Slot1.29 (~NMI); also elsewhere on the board
~RESET: Slot1.31 (~RES); also elsewhere on the board

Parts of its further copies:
Slot0, Slot2, Slot3, Slot4, Slot5, Slot6, Slot7: Expansion Slot; EDAC_395-050-520-201_CounterClockwise

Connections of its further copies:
+5V: Slot0.25 (+5V), Slot2.25 (+5V), Slot3.25 (+5V), Slot4.25 (+5V), Slot5.25 (+5V), Slot6.25 (+5V), Slot7.25 (+5V); also elsewhere on the board
+12V: Slot0.50 (+12V), Slot2.50 (+12V), Slot3.50 (+12V), Slot4.50 (+12V), Slot5.50 (+12V), Slot6.50 (+12V), Slot7.50 (+12V); also elsewhere on the board
-5V: Slot0.34 (-5V), Slot2.34 (-5V), Slot3.34 (-5V), Slot4.34 (-5V), Slot5.34 (-5V), Slot6.34 (-5V), Slot7.34 (-5V); also elsewhere on the board
-12V: Slot0.33 (-12V), Slot2.33 (-12V), Slot3.33 (-12V), Slot4.33 (-12V), Slot5.33 (-12V), Slot6.33 (-12V), Slot7.33 (-12V); also elsewhere on the board
/Slot 0/INT IN: Slot0.28 (INT_IN)
/Slot 0/INT OUT: Slot0.23 (INT_OUT)
/Slot 0/~I/O SELECT: Slot0.1 (~I/O_SELECT)
/Slot 2/INT IN: Slot2.28 (INT_IN)
/Slot 2/INT OUT: Slot2.23 (INT_OUT)
/Slot 3/INT IN: Slot4.28 (INT_IN)
/Slot 3/INT OUT: Slot4.23 (INT_OUT)
/Slot 4/INT IN: Slot5.28 (INT_IN)
/Slot 4/INT OUT: Slot5.23 (INT_OUT)
/Slot 5/INT IN: Slot3.28 (INT_IN)
/Slot 5/INT OUT: Slot3.23 (INT_OUT)
/Slot 6/INT IN: Slot6.28 (INT_IN)
/Slot 6/INT OUT: Slot6.23 (INT_OUT)
/Slot 7/INT IN: Slot7.28 (INT_IN)
/Slot 7/INT OUT: Slot7.23 (INT_OUT)
A0: Slot0.2 (A0), Slot2.2 (A0), Slot3.2 (A0), Slot4.2 (A0), Slot5.2 (A0), Slot6.2 (A0), Slot7.2 (A0); also elsewhere on the board
A1: Slot0.3 (A1), Slot2.3 (A1), Slot3.3 (A1), Slot4.3 (A1), Slot5.3 (A1), Slot6.3 (A1), Slot7.3 (A1); also elsewhere on the board
A2: Slot0.4 (A2), Slot2.4 (A2), Slot3.4 (A2), Slot4.4 (A2), Slot5.4 (A2), Slot6.4 (A2), Slot7.4 (A2); also elsewhere on the board
A3: Slot0.5 (A3), Slot2.5 (A3), Slot3.5 (A3), Slot4.5 (A3), Slot5.5 (A3), Slot6.5 (A3), Slot7.5 (A3); also elsewhere on the board
A4: Slot0.6 (A4), Slot2.6 (A4), Slot3.6 (A4), Slot4.6 (A4), Slot5.6 (A4), Slot6.6 (A4), Slot7.6 (A4); also elsewhere on the board
A5: Slot0.7 (A5), Slot2.7 (A5), Slot3.7 (A5), Slot4.7 (A5), Slot5.7 (A5), Slot6.7 (A5), Slot7.7 (A5); also elsewhere on the board
A6: Slot0.8 (A6), Slot2.8 (A6), Slot3.8 (A6), Slot4.8 (A6), Slot5.8 (A6), Slot6.8 (A6), Slot7.8 (A6); also elsewhere on the board
A7: Slot0.9 (A7), Slot2.9 (A7), Slot3.9 (A7), Slot4.9 (A7), Slot5.9 (A7), Slot6.9 (A7), Slot7.9 (A7); also elsewhere on the board
A8: Slot0.10 (A8), Slot2.10 (A8), Slot3.10 (A8), Slot4.10 (A8), Slot5.10 (A8), Slot6.10 (A8), Slot7.10 (A8); also elsewhere on the board
A9: Slot0.11 (A9), Slot2.11 (A9), Slot3.11 (A9), Slot4.11 (A9), Slot5.11 (A9), Slot6.11 (A9), Slot7.11 (A9); also elsewhere on the board
A10: Slot0.12 (A10), Slot2.12 (A10), Slot3.12 (A10), Slot4.12 (A10), Slot5.12 (A10), Slot6.12 (A10), Slot7.12 (A10); also elsewhere on the board
A11: Slot0.13 (A11), Slot2.13 (A11), Slot3.13 (A11), Slot4.13 (A11), Slot5.13 (A11), Slot6.13 (A11), Slot7.13 (A11); also elsewhere on the board
A12: Slot0.14 (A12), Slot2.14 (A12), Slot3.14 (A12), Slot4.14 (A12), Slot5.14 (A12), Slot6.14 (A12), Slot7.14 (A12); also elsewhere on the board
A13: Slot0.15 (A13), Slot2.15 (A13), Slot3.15 (A13), Slot4.15 (A13), Slot5.15 (A13), Slot6.15 (A13), Slot7.15 (A13); also elsewhere on the board
A14: Slot0.16 (A14), Slot2.16 (A14), Slot3.16 (A14), Slot4.16 (A14), Slot5.16 (A14), Slot6.16 (A14), Slot7.16 (A14); also elsewhere on the board
A15: Slot0.17 (A15), Slot2.17 (A15), Slot3.17 (A15), Slot4.17 (A15), Slot5.17 (A15), Slot6.17 (A15), Slot7.17 (A15); also elsewhere on the board
D0: Slot0.49 (D0), Slot2.49 (D0), Slot3.49 (D0), Slot4.49 (D0), Slot5.49 (D0), Slot6.49 (D0), Slot7.49 (D0); also elsewhere on the board
D1: Slot0.48 (D1), Slot2.48 (D1), Slot3.48 (D1), Slot4.48 (D1), Slot5.48 (D1), Slot6.48 (D1), Slot7.48 (D1); also elsewhere on the board
D2: Slot0.47 (D2), Slot2.47 (D2), Slot3.47 (D2), Slot4.47 (D2), Slot5.47 (D2), Slot6.47 (D2), Slot7.47 (D2); also elsewhere on the board
D3: Slot0.46 (D3), Slot2.46 (D3), Slot3.46 (D3), Slot4.46 (D3), Slot5.46 (D3), Slot6.46 (D3), Slot7.46 (D3); also elsewhere on the board
D4: Slot0.45 (D4), Slot2.45 (D4), Slot3.45 (D4), Slot4.45 (D4), Slot5.45 (D4), Slot6.45 (D4), Slot7.45 (D4); also elsewhere on the board
D5: Slot0.44 (D5), Slot2.44 (D5), Slot3.44 (D5), Slot4.44 (D5), Slot5.44 (D5), Slot6.44 (D5), Slot7.44 (D5); also elsewhere on the board
D6: Slot0.43 (D6), Slot2.43 (D6), Slot3.43 (D6), Slot4.43 (D6), Slot5.43 (D6), Slot6.43 (D6), Slot7.43 (D6); also elsewhere on the board
D7: Slot0.42 (D7), Slot2.42 (D7), Slot3.42 (D7), Slot4.42 (D7), Slot5.42 (D7), Slot6.42 (D7), Slot7.42 (D7); also elsewhere on the board
GND: Slot0.26 (GND), Slot2.26 (GND), Slot3.26 (GND), Slot4.26 (GND), Slot5.26 (GND), Slot6.26 (GND), Slot7.26 (GND); also elsewhere on the board
PHASE 0: Slot0.40 (Φ0), Slot2.40 (Φ0), Slot3.40 (Φ0), Slot4.40 (Φ0), Slot5.40 (Φ0), Slot6.40 (Φ0), Slot7.40 (Φ0); also elsewhere on the board
PHASE 1: Slot0.38 (Φ1), Slot2.38 (Φ1), Slot3.38 (Φ1), Slot4.38 (Φ1), Slot5.38 (Φ1), Slot6.38 (Φ1), Slot7.38 (Φ1); also elsewhere on the board
Q3: Slot0.37 (Q3), Slot2.37 (Q3), Slot3.37 (Q3), Slot4.37 (Q3), Slot5.37 (Q3), Slot6.37 (Q3), Slot7.37 (Q3); also elsewhere on the board
RDY: Slot0.21 (RDY), Slot2.21 (RDY), Slot3.21 (RDY), Slot4.21 (RDY), Slot5.21 (RDY), Slot6.21 (RDY), Slot7.21 (RDY); also elsewhere on the board
R/~W: Slot0.18 (R/~W), Slot2.18 (R/~W), Slot3.18 (R/~W), Slot4.18 (R/~W), Slot5.18 (R/~W), Slot6.18 (R/~W), Slot7.18 (R/~W); also elsewhere on the board
~DEVICE SELECT 0: Slot0.41 (~DEVICE_SELECT); also elsewhere on the board
~DEVICE SELECT 2: Slot2.41 (~DEVICE_SELECT); also elsewhere on the board
~DEVICE SELECT 3: Slot4.41 (~DEVICE_SELECT); also elsewhere on the board
~DEVICE SELECT 4: Slot5.41 (~DEVICE_SELECT); also elsewhere on the board
~DEVICE SELECT 5: Slot3.41 (~DEVICE_SELECT); also elsewhere on the board
~DEVICE SELECT 6: Slot6.41 (~DEVICE_SELECT); also elsewhere on the board
~DEVICE SELECT 7: Slot7.41 (~DEVICE_SELECT); also elsewhere on the board
~INH: Slot0.32 (~INH), Slot2.32 (~INH), Slot3.32 (~INH), Slot4.32 (~INH), Slot5.32 (~INH), Slot6.32 (~INH), Slot7.32 (~INH); also elsewhere on the board
~IRQ: Slot0.30 (~IRQ), Slot2.30 (~IRQ), Slot3.30 (~IRQ), Slot4.30 (~IRQ), Slot5.30 (~IRQ), Slot6.30 (~IRQ), Slot7.30 (~IRQ); also elsewhere on the board
~I/O SELECT 2: Slot2.1 (~I/O_SELECT); also elsewhere on the board
~I/O SELECT 3: Slot4.1 (~I/O_SELECT); also elsewhere on the board
~I/O SELECT 4: Slot5.1 (~I/O_SELECT); also elsewhere on the board
~I/O SELECT 5: Slot3.1 (~I/O_SELECT); also elsewhere on the board
~I/O SELECT 6: Slot6.1 (~I/O_SELECT); also elsewhere on the board
~I/O SELECT 7: Slot7.1 (~I/O_SELECT); also elsewhere on the board
~I/O STROBE: Slot0.20 (~I/O_STROBE), Slot2.20 (~I/O_STROBE), Slot3.20 (~I/O_STROBE), Slot4.20 (~I/O_STROBE), Slot5.20 (~I/O_STROBE), Slot6.20 (~I/O_STROBE), Slot7.20 (~I/O_STROBE); also elsewhere on the board
~NMI: Slot0.29 (~NMI), Slot2.29 (~NMI), Slot3.29 (~NMI), Slot4.29 (~NMI), Slot5.29 (~NMI), Slot6.29 (~NMI), Slot7.29 (~NMI); also elsewhere on the board
~RESET: Slot0.31 (~RES), Slot2.31 (~RES), Slot3.31 (~RES), Slot4.31 (~RES), Slot5.31 (~RES), Slot6.31 (~RES), Slot7.31 (~RES); also elsewhere on the board

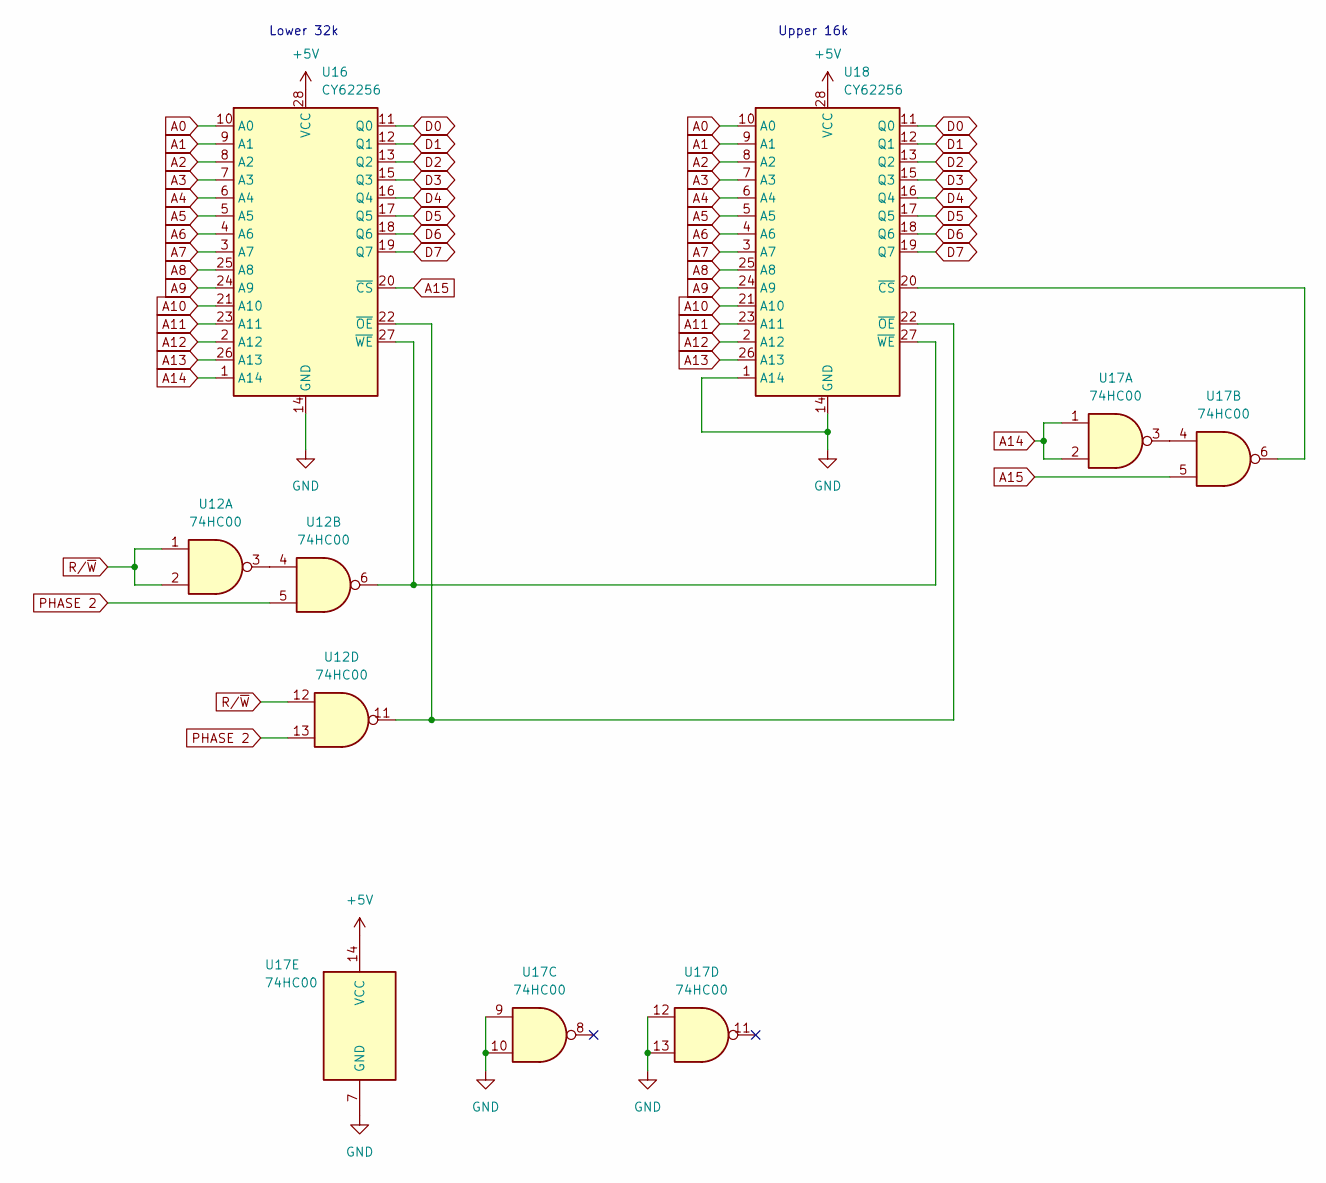
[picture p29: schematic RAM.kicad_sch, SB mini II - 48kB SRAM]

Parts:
U12, U17: 74HC00; DIP-14_W7.62mm_LongPads
U16, U18: CY62256; DIP-28_W7.62mm_LongPads

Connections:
+5V: U16.28 (VCC), U17.14 (VCC), U18.28 (VCC); also elsewhere on the board
A0: U16.10 (A0), U18.10 (A0); also elsewhere on the board
A1: U16.9 (A1), U18.9 (A1); also elsewhere on the board
A2: U16.8 (A2), U18.8 (A2); also elsewhere on the board
A3: U16.7 (A3), U18.7 (A3); also elsewhere on the board
A4: U16.6 (A4), U18.6 (A4); also elsewhere on the board
A5: U16.5 (A5), U18.5 (A5); also elsewhere on the board
A6: U16.4 (A6), U18.4 (A6); also elsewhere on the board
A7: U16.3 (A7), U18.3 (A7); also elsewhere on the board
A8: U16.25 (A8), U18.25 (A8); also elsewhere on the board
A9: U16.24 (A9), U18.24 (A9); also elsewhere on the board
A10: U16.21 (A10), U18.21 (A10); also elsewhere on the board
A11: U16.23 (A11), U18.23 (A11); also elsewhere on the board
A12: U16.2 (A12), U18.2 (A12); also elsewhere on the board
A13: U16.26 (A13), U18.26 (A13); also elsewhere on the board
A14: U16.1 (A14), U17.1, U17.2; also elsewhere on the board
A15: U16.20 (~CS), U17.5; also elsewhere on the board
D0: U16.11 (Q0), U18.11 (Q0); also elsewhere on the board
D1: U16.12 (Q1), U18.12 (Q1); also elsewhere on the board
D2: U16.13 (Q2), U18.13 (Q2); also elsewhere on the board
D3: U16.15 (Q3), U18.15 (Q3); also elsewhere on the board
D4: U16.16 (Q4), U18.16 (Q4); also elsewhere on the board
D5: U16.17 (Q5), U18.17 (Q5); also elsewhere on the board
D6: U16.18 (Q6), U18.18 (Q6); also elsewhere on the board
D7: U16.19 (Q7), U18.19 (Q7); also elsewhere on the board
GND: U16.14 (GND), U17.7 (GND), U17.9, U17.10, U17.12, U17.13, U18.1 (A14), U18.14 (GND); also elsewhere on the board
unnamed: U12.3, U12.4
unnamed: U12.11, U16.22 (~OE), U18.22 (~OE)
unnamed: U12.6, U16.27 (~WE), U18.27 (~WE)
unnamed: U17.3, U17.4
unnamed: U17.6, U18.20 (~CS)
PHASE 2: U12.5, U12.13; also elsewhere on the board
R/~W: U12.1, U12.2, U12.12; also elsewhere on the board

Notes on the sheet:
Upper 16k
Lower 32k

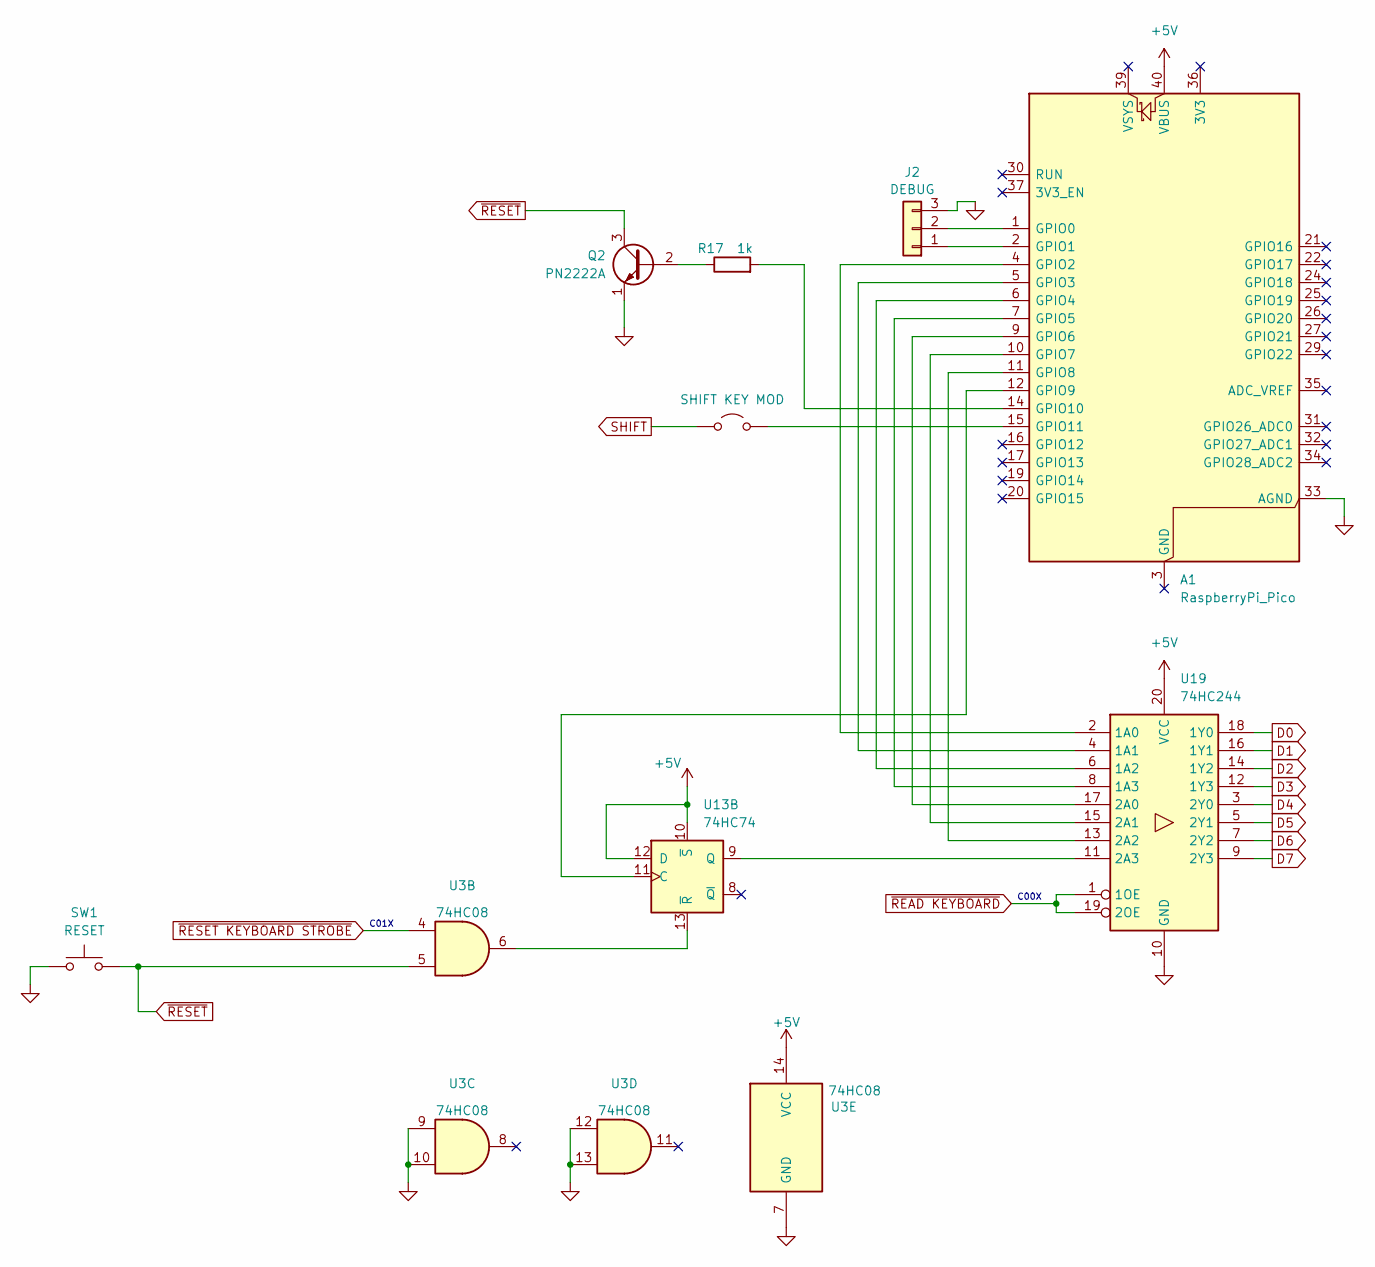
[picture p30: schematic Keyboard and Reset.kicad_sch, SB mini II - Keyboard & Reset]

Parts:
A1: RaspberryPi_Pico; RaspberryPi_Pico_Common_Unspecified
J2: DEBUG; PinHeader_1x03_P2.54mm_Vertical
JP2: SHIFT KEY MOD; TestPoint_2Pads_Pitch2.54mm_Drill0.8mm
Q2: PN2222A; TO-92L_HandSolder
R17: 1k; R_Axial_DIN0207_L6.3mm_D2.5mm_P7.62mm_Horizontal
SW1: RESET; SW_PUSH_1P1T_6x3.5mm_H5.0_APEM_MJTP1250
U3: 74HC08; DIP-14_W7.62mm_LongPads
U13: 74HC74; DIP-14_W7.62mm_LongPads
U19: 74HC244; DIP-20_W7.62mm_LongPads

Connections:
+5V: A1.40 (VBUS), U3.14 (VCC), U13.10 (~S), U13.12 (D), U19.20 (VCC); also elsewhere on the board
D0: U19.18 (1Y0); also elsewhere on the board
D1: U19.16 (1Y1); also elsewhere on the board
D2: U19.14 (1Y2); also elsewhere on the board
D3: U19.12 (1Y3); also elsewhere on the board
D4: U19.3 (2Y0); also elsewhere on the board
D5: U19.5 (2Y1); also elsewhere on the board
D6: U19.7 (2Y2); also elsewhere on the board
D7: U19.9 (2Y3); also elsewhere on the board
GND: A1.33 (AGND), J2.3, Q2.1 (E), SW1.1, U3.7 (GND), U3.9, U3.10, U3.12, U3.13, U19.10 (GND); also elsewhere on the board
unnamed: A1.1 (GPIO0), J2.2
unnamed: A1.2 (GPIO1), J2.1
unnamed: A1.4 (GPIO2), U19.2 (1A0)
unnamed: A1.5 (GPIO3), U19.4 (1A1)
unnamed: A1.6 (GPIO4), U19.6 (1A2)
unnamed: A1.7 (GPIO5), U19.8 (1A3)
unnamed: A1.9 (GPIO6), U19.17 (2A0)
unnamed: A1.10 (GPIO7), U19.15 (2A1)
unnamed: A1.11 (GPIO8), U19.13 (2A2)
unnamed: A1.12 (GPIO9), U13.11 (C)
unnamed: A1.14 (GPIO10), R17.2
unnamed: A1.15 (GPIO11), JP2.2 (B)
unnamed: Q2.2 (B), R17.1
unnamed: U13.9 (Q), U19.11 (2A3)
unnamed: U3.6, U13.13 (~R)
SHIFT: JP2.1 (A); also elsewhere on the board
~READ KEYBOARD: U19.1 (1OE), U19.19 (2OE); also elsewhere on the board
~RESET KEYBOARD STROBE: U3.4; also elsewhere on the board
~RESET: Q2.3 (C), SW1.2, U3.5; also elsewhere on the board

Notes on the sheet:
C00X
C01X

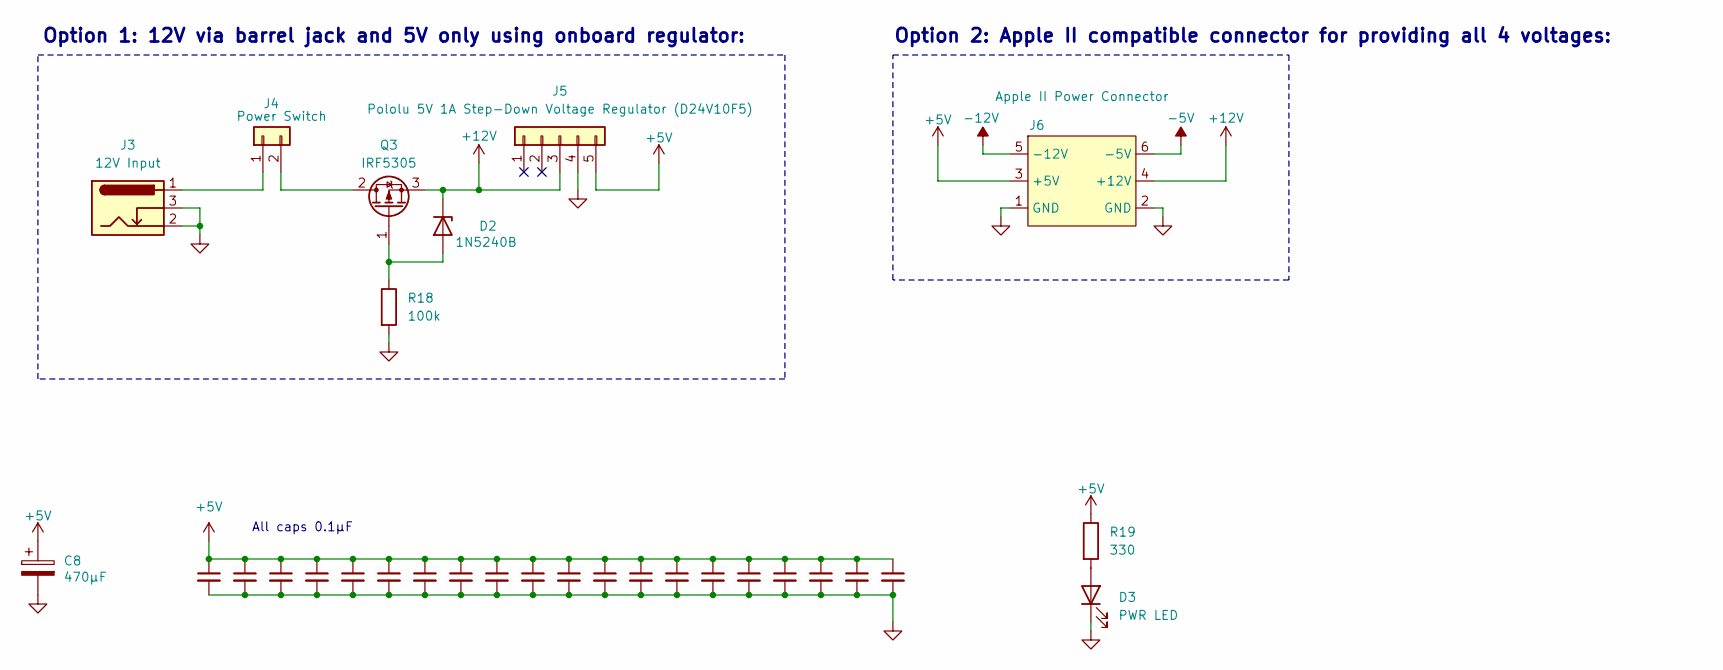
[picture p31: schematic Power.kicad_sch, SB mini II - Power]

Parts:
C8: 470µF; CP_Radial_D6.3mm_P2.50mm
C9, C10, C11, C12, C13, C14, C15, C16, C17, C18, C19, C20, C21, C22, C23, C24, C25, C26, C27, C28: 0.1µF; R_Axial_DIN0204_L3.6mm_D1.6mm_P5.08mm_Horizontal
D2: 1N5240B; D_DO-41_SOD81_P10.16mm_Horizontal
D3: PWR LED; LED_D5.0mm
J3: 12V Input; BarrelJack_Horizontal
J4: Power Switch; TerminalBlock_MaiXu_MX126-5.0-02P_1x02_P5.00mm
J5: Pololu 5V 1A Step-Down Voltage Regulator (D24V10F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; PinSocket_1x05_P2.54mm_Vertical
J6: Apple II Power Connector; 1-640520-0_Power_Connector
Q3: IRF5305; TO-220-3_Vertical
R18: 100k; R_Axial_DIN0207_L6.3mm_D2.5mm_P7.62mm_Horizontal
R19: 330; R_Axial_DIN0207_L6.3mm_D2.5mm_P7.62mm_Horizontal

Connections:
+5V: C8.1, C9.1, C10.1, C11.1, C12.1, C13.1, C14.1, C15.1, C16.1, C17.1, C18.1, C19.1, C20.1, C21.1, C22.1, C23.1, C24.1, C25.1, C26.1, C27.1, C28.1, J5.5, J6.3 (+5V), R19.1; also elsewhere on the board
+12V: D2.1 (K), J5.3, J6.4 (+12V), Q3.3 (S); also elsewhere on the board
-5V: J6.6 (-5V); also elsewhere on the board
-12V: J6.5 (-12V); also elsewhere on the board
GND: C8.2, C9.2, C10.2, C11.2, C12.2, C13.2, C14.2, C15.2, C16.2, C17.2, C18.2, C19.2, C20.2, C21.2, C22.2, C23.2, C24.2, C25.2, C26.2, C27.2, C28.2, D3.1 (K), J3.2, J3.3, J5.4, J6.1 (GND), J6.2 (GND), R18.2; also elsewhere on the board
unnamed: D2.2 (A), Q3.1 (G), R18.1
unnamed: D3.2 (A), R19.2
unnamed: J3.1, J4.1
unnamed: J4.2, Q3.2 (D)

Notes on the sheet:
All caps 0.1µF
Option 1: 12V via barrel jack and 5V only using onboard regulator:
Option 2: Apple II compatible connector for providing all 4 voltages:

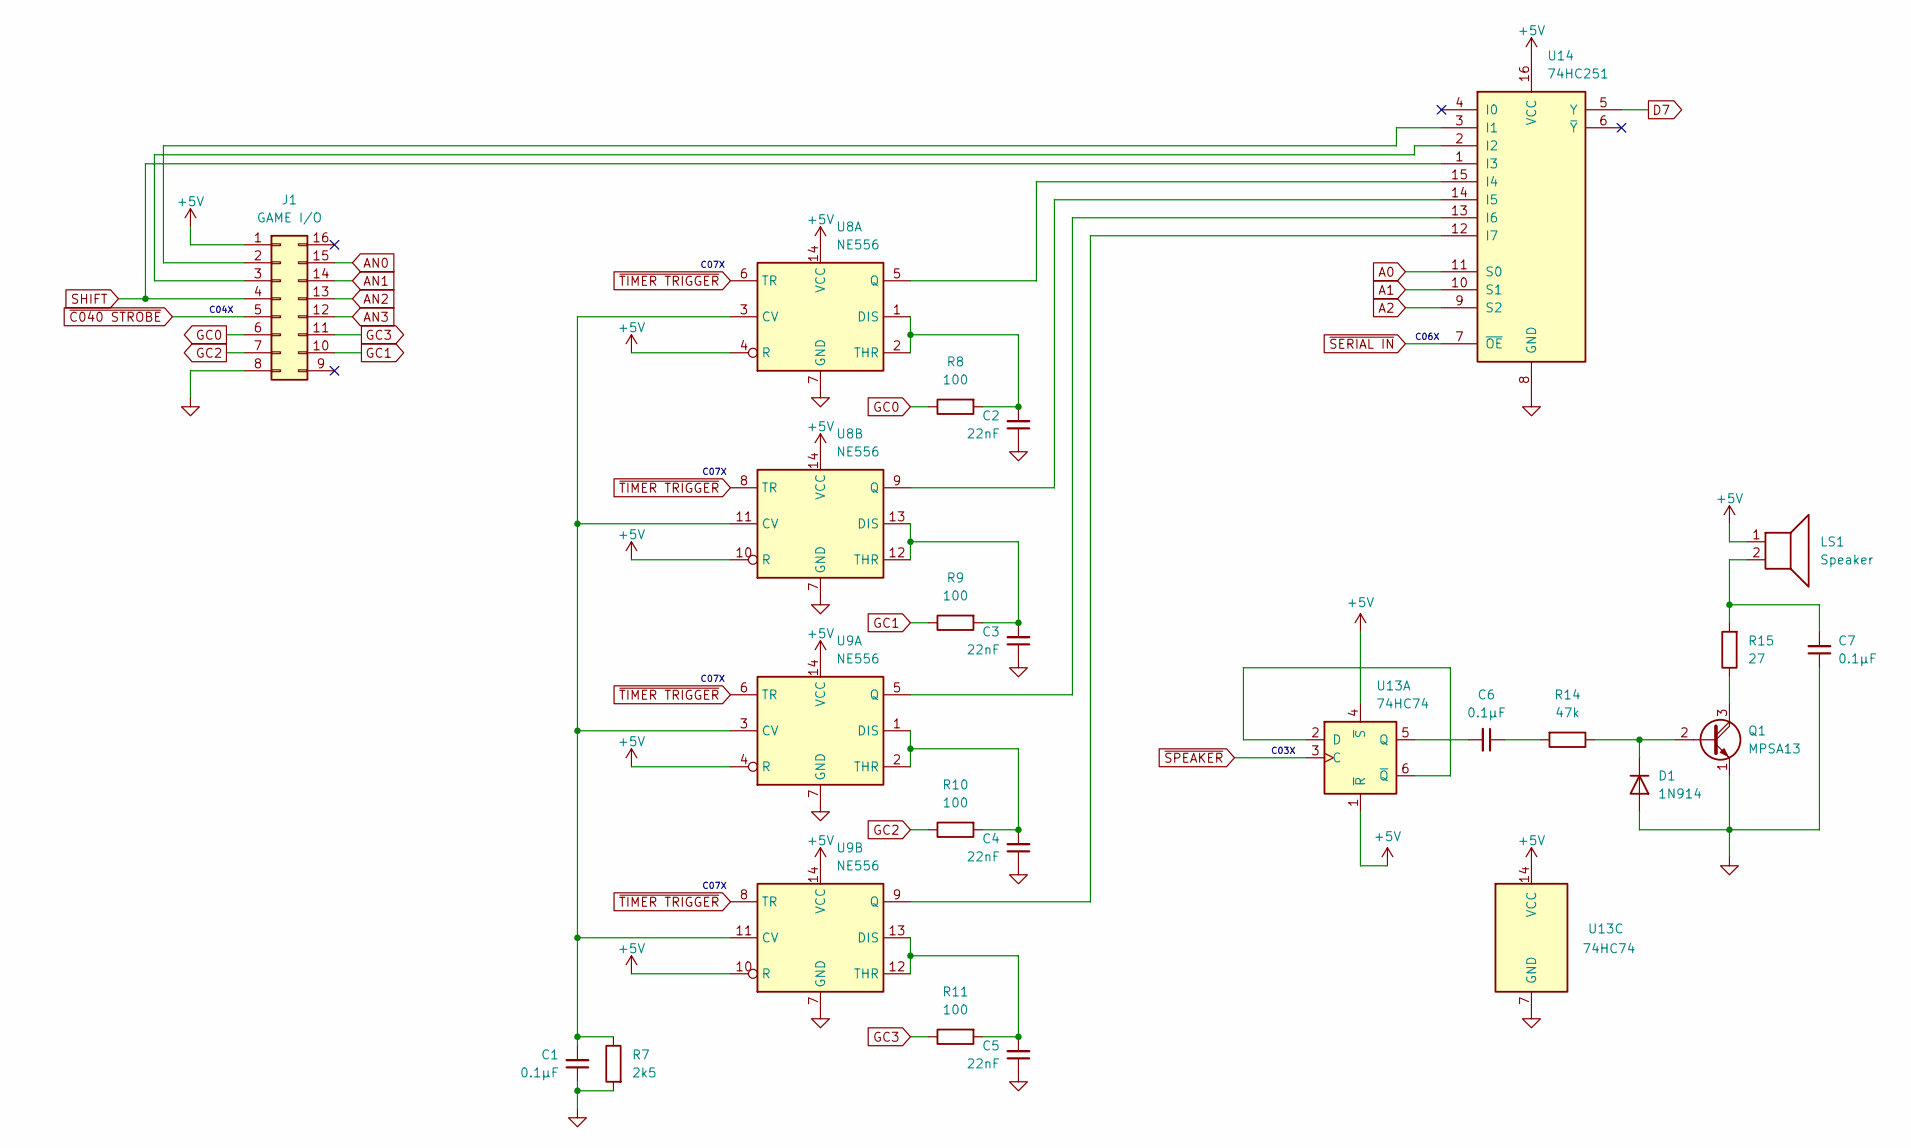
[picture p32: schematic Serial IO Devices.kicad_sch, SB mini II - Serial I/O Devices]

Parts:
C1, C6, C7: 0.1µF; R_Axial_DIN0204_L3.6mm_D1.6mm_P5.08mm_Horizontal
C2, C3, C4, C5: 22nF; R_Axial_DIN0204_L3.6mm_D1.6mm_P5.08mm_Horizontal
D1: 1N914; D_DO-35_SOD27_P7.62mm_Horizontal
J1: GAME I/O; DIP-16_W7.62mm_Socket_LongPads
LS1: Speaker; Molex_KK-254_AE-6410-02A_1x02_P2.54mm_Vertical
Q1: MPSA13; TO-92L_HandSolder
R7: 2k5; R_Axial_DIN0207_L6.3mm_D2.5mm_P7.62mm_Horizontal
R8, R9, R10, R11: 100; R_Axial_DIN0207_L6.3mm_D2.5mm_P7.62mm_Horizontal
R14: 47k; R_Axial_DIN0207_L6.3mm_D2.5mm_P7.62mm_Horizontal
R15: 27; R_Axial_DIN0207_L6.3mm_D2.5mm_P7.62mm_Horizontal
U8, U9: NE556; DIP-14_W7.62mm_LongPads
U13: 74HC74; DIP-14_W7.62mm_LongPads
U14: 74HC251; DIP-16_W7.62mm_LongPads

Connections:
+5V: J1.1, LS1.1, U8.4 (R), U8.10 (R), U8.14 (VCC), U9.4 (R), U9.10 (R), U9.14 (VCC), U13.1 (~R), U13.4 (~S), U13.14 (VCC), U14.16 (VCC); also elsewhere on the board
A0: U14.11 (S0); also elsewhere on the board
A1: U14.10 (S1); also elsewhere on the board
A2: U14.9 (S2); also elsewhere on the board
AN0: J1.15; also elsewhere on the board
AN1: J1.14; also elsewhere on the board
AN2: J1.13; also elsewhere on the board
AN3: J1.12; also elsewhere on the board
D7: U14.5 (Y); also elsewhere on the board
GC0: J1.6, R8.1
GC1: J1.10, R9.1
GC2: J1.7, R10.1
GC3: J1.11, R11.1
GND: C1.1, C2.1, C3.1, C4.1, C5.1, C7.1, D1.2 (A), J1.8, Q1.1 (E), R7.2, U8.7 (GND), U9.7 (GND), U13.7 (GND), U14.8 (GND); also elsewhere on the board
unnamed: C6.1, R14.2
unnamed: C7.2, LS1.2, R15.2
unnamed: D1.1 (K), Q1.2 (B), R14.1
unnamed: J1.2, U14.3 (I1)
unnamed: J1.3, U14.2 (I2)
unnamed: Q1.3 (C), R15.1
unnamed: C1.2, R7.1, U8.3 (CV), U8.11 (CV), U9.3 (CV), U9.11 (CV)
unnamed: C2.2, R8.2, U8.1 (DIS), U8.2 (THR)
unnamed: C3.2, R9.2, U8.12 (THR), U8.13 (DIS)
unnamed: C4.2, R10.2, U9.1 (DIS), U9.2 (THR)
unnamed: C5.2, R11.2, U9.12 (THR), U9.13 (DIS)
unnamed: U13.2 (D), U13.6 (~Q)
unnamed: C6.2, U13.5 (Q)
unnamed: U8.5 (Q), U14.15 (I4)
unnamed: U8.9 (Q), U14.14 (I5)
unnamed: U9.5 (Q), U14.13 (I6)
unnamed: U9.9 (Q), U14.12 (I7)
SHIFT: J1.4, U14.1 (I3); also elsewhere on the board
~C040 STROBE: J1.5; also elsewhere on the board
~SERIAL IN: U14.7 (~OE); also elsewhere on the board
~SPEAKER: U13.3 (C); also elsewhere on the board
~TIMER TRIGGER: U8.6 (TR), U8.8 (TR), U9.6 (TR), U9.8 (TR); also elsewhere on the board

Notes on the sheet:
C07X
C03X
C06X
C04X

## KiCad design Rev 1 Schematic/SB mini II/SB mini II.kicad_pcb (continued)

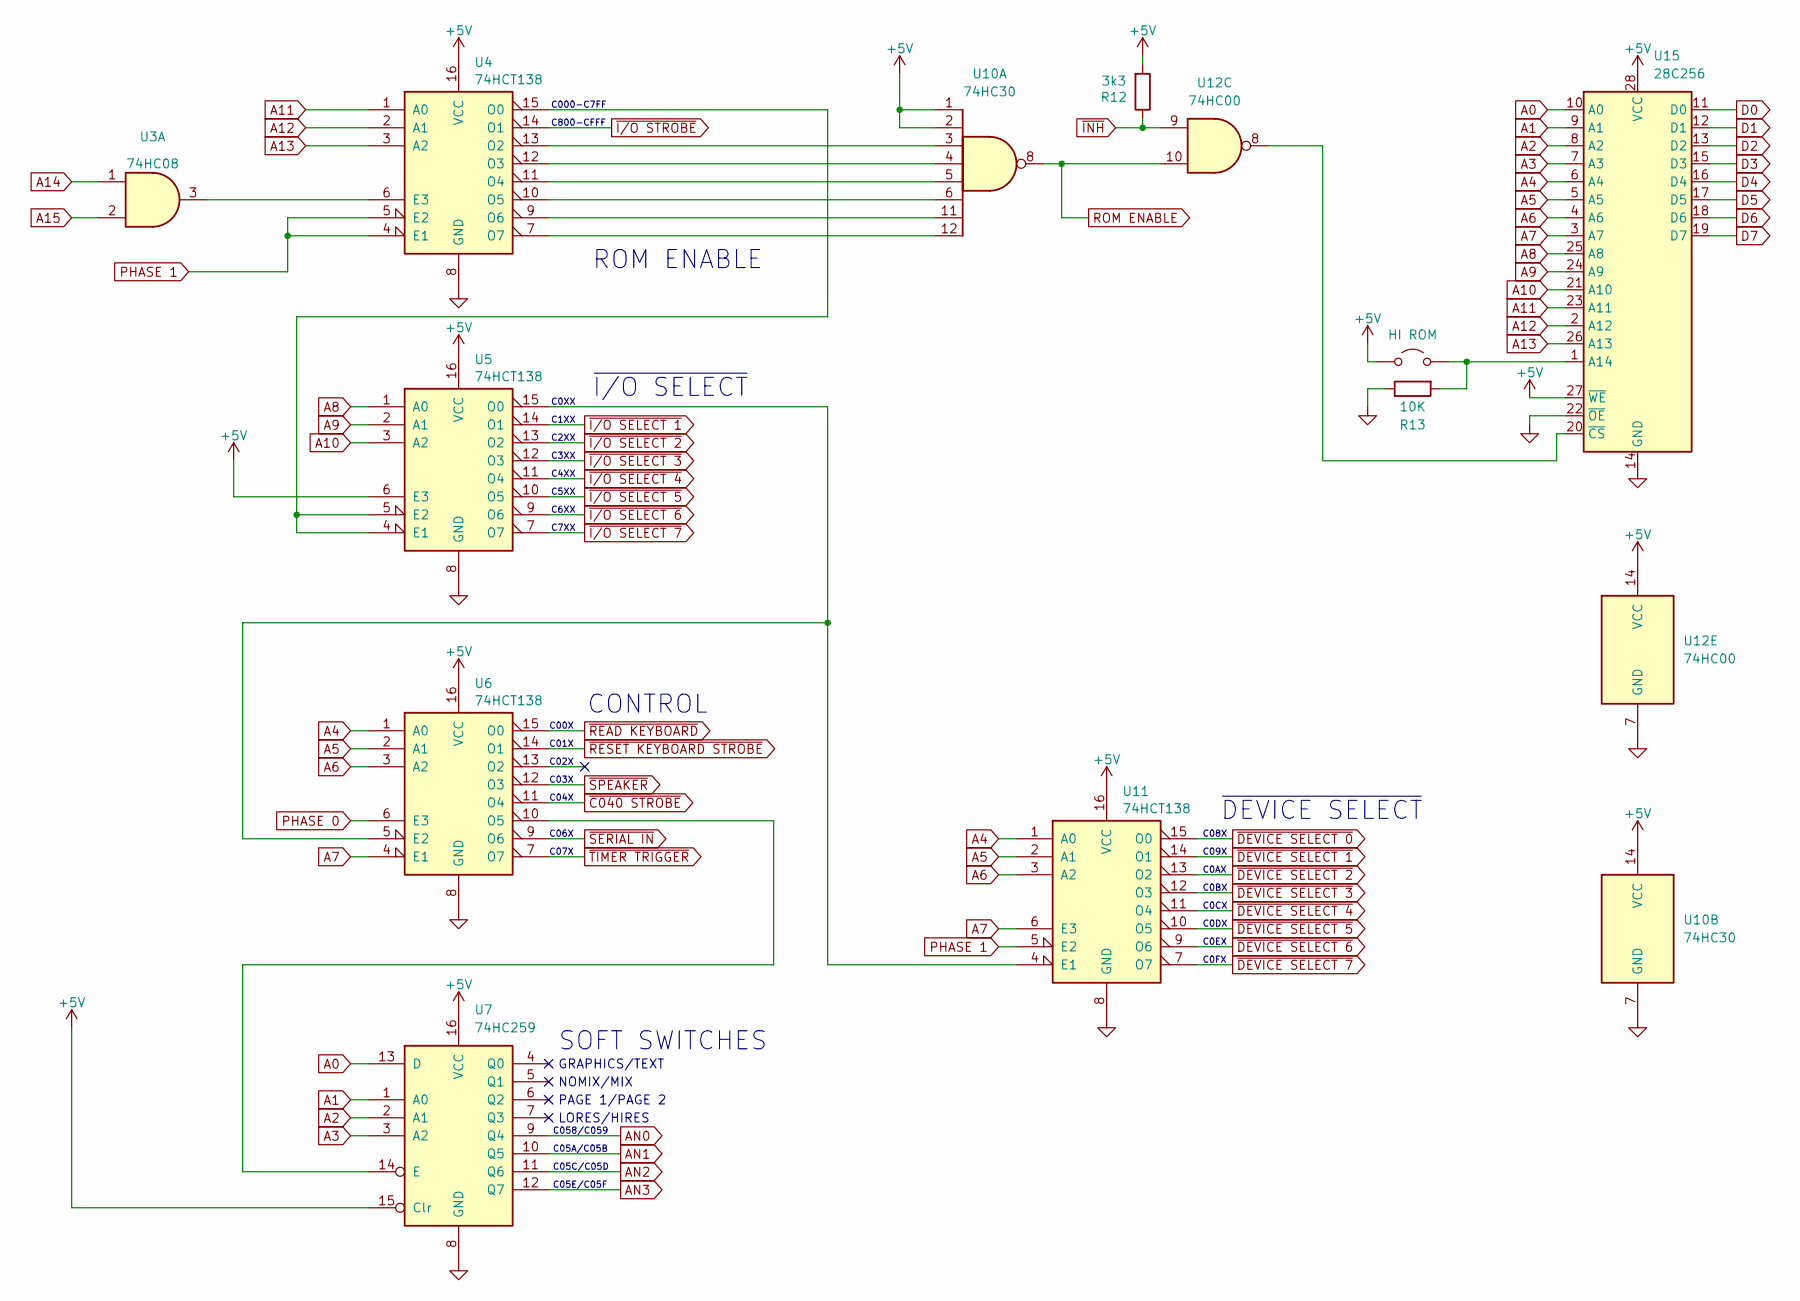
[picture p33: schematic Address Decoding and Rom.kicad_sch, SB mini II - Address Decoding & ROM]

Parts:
JP1: HI ROM; TestPoint_2Pads_Pitch2.54mm_Drill0.8mm
R12: 3k3; R_Axial_DIN0207_L6.3mm_D2.5mm_P7.62mm_Horizontal
R13: 10K; R_Axial_DIN0207_L6.3mm_D2.5mm_P7.62mm_Horizontal
U3: 74HC08; DIP-14_W7.62mm_LongPads
U4, U5, U6, U11: 74HCT138; DIP-16_W7.62mm_LongPads
U7: 74HC259; DIP-16_W7.62mm_LongPads
U10: 74HC30; DIP-14_W7.62mm_LongPads
U12: 74HC00; DIP-14_W7.62mm_LongPads
U15: 28C256; DIP-28_W15.24mm_LongPads

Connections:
+5V: JP1.1 (A), R12.2, U4.16 (VCC), U5.6 (E3), U5.16 (VCC), U6.16 (VCC), U7.15 (Clr), U7.16 (VCC), U10.1, U10.2, U10.14 (VCC), U11.16 (VCC), U12.14 (VCC), U15.27 (~WE), U15.28 (VCC); also elsewhere on the board
A0: U7.13 (D), U15.10 (A0); also elsewhere on the board
A1: U7.1 (A0), U15.9 (A1); also elsewhere on the board
A2: U7.2 (A1), U15.8 (A2); also elsewhere on the board
A3: U7.3 (A2), U15.7 (A3); also elsewhere on the board
A4: U6.1 (A0), U11.1 (A0), U15.6 (A4); also elsewhere on the board
A5: U6.2 (A1), U11.2 (A1), U15.5 (A5); also elsewhere on the board
A6: U6.3 (A2), U11.3 (A2), U15.4 (A6); also elsewhere on the board
A7: U6.4 (E1), U11.6 (E3), U15.3 (A7); also elsewhere on the board
A8: U5.1 (A0), U15.25 (A8); also elsewhere on the board
A9: U5.2 (A1), U15.24 (A9); also elsewhere on the board
A10: U5.3 (A2), U15.21 (A10); also elsewhere on the board
A11: U4.1 (A0), U15.23 (A11); also elsewhere on the board
A12: U4.2 (A1), U15.2 (A12); also elsewhere on the board
A13: U4.3 (A2), U15.26 (A13); also elsewhere on the board
A14: U3.1; also elsewhere on the board
A15: U3.2; also elsewhere on the board
AN0: U7.9 (Q4); also elsewhere on the board
AN1: U7.10 (Q5); also elsewhere on the board
AN2: U7.11 (Q6); also elsewhere on the board
AN3: U7.12 (Q7); also elsewhere on the board
D0: U15.11 (D0); also elsewhere on the board
D1: U15.12 (D1); also elsewhere on the board
D2: U15.13 (D2); also elsewhere on the board
D3: U15.15 (D3); also elsewhere on the board
D4: U15.16 (D4); also elsewhere on the board
D5: U15.17 (D5); also elsewhere on the board
D6: U15.18 (D6); also elsewhere on the board
D7: U15.19 (D7); also elsewhere on the board
GND: R13.1, U4.8 (GND), U5.8 (GND), U6.8 (GND), U7.8 (GND), U10.7 (GND), U11.8 (GND), U12.7 (GND), U15.14 (GND), U15.22 (~OE); also elsewhere on the board
unnamed: JP1.2 (B), R13.2, U15.1 (A14)
unnamed: U3.3, U4.6 (E3)
unnamed: U4.15 (O0), U5.4 (E1), U5.5 (E2)
unnamed: U4.13 (O2), U10.3
unnamed: U4.12 (O3), U10.4
unnamed: U4.11 (O4), U10.5
unnamed: U4.10 (O5), U10.6
unnamed: U4.9 (O6), U10.11
unnamed: U4.7 (O7), U10.12
unnamed: U6.10 (O5), U7.14 (E)
unnamed: U5.15 (O0), U6.5 (E2), U11.4 (E1)
unnamed: U12.8, U15.20 (~CS)
PHASE 0: U6.6 (E3); also elsewhere on the board
PHASE 1: U4.4 (E1), U4.5 (E2), U11.5 (E2); also elsewhere on the board
ROM ENABLE: U10.8, U12.10
~C040 STROBE: U6.11 (O4); also elsewhere on the board
~DEVICE SELECT 0: U11.15 (O0); also elsewhere on the board
~DEVICE SELECT 1: U11.14 (O1); also elsewhere on the board
~DEVICE SELECT 2: U11.13 (O2); also elsewhere on the board
~DEVICE SELECT 3: U11.12 (O3); also elsewhere on the board
~DEVICE SELECT 4: U11.11 (O4); also elsewhere on the board
~DEVICE SELECT 5: U11.10 (O5); also elsewhere on the board
~DEVICE SELECT 6: U11.9 (O6); also elsewhere on the board
~DEVICE SELECT 7: U11.7 (O7); also elsewhere on the board
~INH: R12.1, U12.9; also elsewhere on the board
~I/O SELECT 1: U5.14 (O1); also elsewhere on the board
~I/O SELECT 2: U5.13 (O2); also elsewhere on the board
~I/O SELECT 3: U5.12 (O3); also elsewhere on the board
~I/O SELECT 4: U5.11 (O4); also elsewhere on the board
~I/O SELECT 5: U5.10 (O5); also elsewhere on the board
~I/O SELECT 6: U5.9 (O6); also elsewhere on the board
~I/O SELECT 7: U5.7 (O7); also elsewhere on the board
~I/O STROBE: U4.14 (O1); also elsewhere on the board
~READ KEYBOARD: U6.15 (O0); also elsewhere on the board
~RESET KEYBOARD STROBE: U6.14 (O1); also elsewhere on the board
~SERIAL IN: U6.9 (O6); also elsewhere on the board
~SPEAKER: U6.12 (O3); also elsewhere on the board
~TIMER TRIGGER: U6.7 (O7); also elsewhere on the board

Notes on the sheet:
GRAPHICS/TEXT
C07X
C1XX
C0AX
C800-CFFF
C08X
C4XX
C000-C7FF
C05E/C05F
C0FX
C058/C059
C2XX
CONTROL
LORES/HIRES
C0XX
C09X
C0CX
C01X
~{DEVICE SELECT}
ROM ENABLE
C04X
C6XX
C06X
C05C/C05D
PAGE 1/PAGE 2
C00X
C05A/C05B
C0BX
C0DX
C0EX
NOMIX/MIX
C5XX
SOFT SWITCHES
C7XX
C03X
C3XX
~{I/O SELECT}
C02X

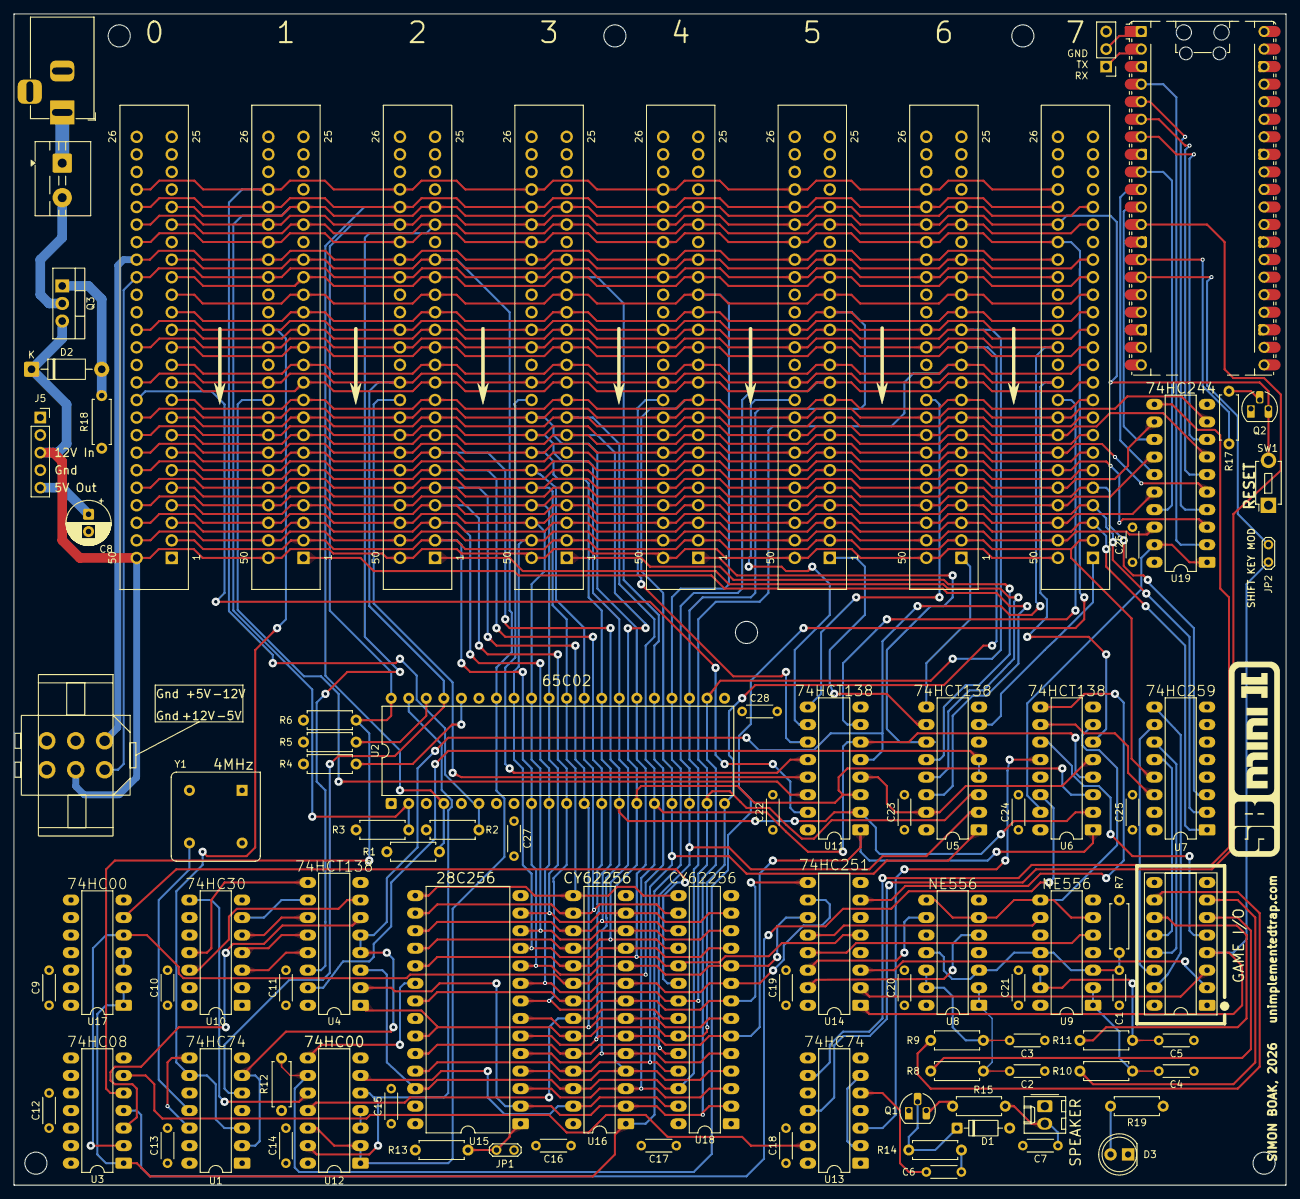
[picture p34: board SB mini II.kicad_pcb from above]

Board: 4 copper layers, 184.2 x 169.5 mm, 97 parts (0 on the bottom side), 128 nets.

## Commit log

2026-06-23 Initial project files
    [Address Decoding and Rom.kicad_sch, BOM.csv, Badge.stp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]
2026-06-27 Adding archive of KiCad schematics
2026-08-07 Adding 3D files for Rev1 case and optional rear with reset switch
    [Front - Rev 1.stp, Front.stp, Left Side - Rev 1.stp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]
2026-08-10 Fixing trace shorting to reset switch
    [SB mini II-B_Cu.gbr, SB mini II-B_Mask.gbr, SB mini II-B_Paste.gbr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]
2026-08-16 Removed R16 from BOM
    (It had already been taken out the Rev1 schematic)
    [BOM.csv]
